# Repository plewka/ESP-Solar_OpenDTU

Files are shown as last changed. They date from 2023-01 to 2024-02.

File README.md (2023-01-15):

# ESP-Solar_OpenDTU
PCB for OpenDTU in Cable Branchbox, LineSupply w. Fuses, RS485/RS232-Olimex, Relais, DS2485 OneWire, I2C-Header...

Mechanically fits into quite compact HNS 989861-H01 wiring box (form closure only).
If not all features are used, even edged Wieland-Socket should fit.
LEDs need LightGuides: no. position-drawing and not included in material list 

Tradeoff: Very limited space, copyrighted code for ds2485

image::ESP-SolarV1.jpg

* WESP32-WROOM-based (internal or external antenna)

* 5x20 Fuseholder (Supply)
* Varistor
* HiLink Supplymodule f.e. 230V->3.3V

* 5x20 Fuseholder (Relais)
* Relais SANYOU 10A

* modern 1Wire-Controler DS2485
* programming Header (Shelly-Pinout)
* I2C+VCC+GND header
* 2x5 Ribbon Connector for Olimex' RS485/RS232-Modules
* LEDs (green: power, red:active, or:DS2485 GPIO)

* TTL serial connector f.e. for IR-Energy reading 
* robust cage clamps for external connections

The board was done for differend scenarios including HoymilesDTU, using different RF-Modules,
reading the new IR-Energy counters with "Volkszähler", measure distributed temerature locations 
with OneWire-Sensors and control of pool pump or heating elements, maybe some IR motion detection 
in the garage, interfacing RS485/Modbus/RS232 for Solar-Inverters etc. - CAN- and metering bus 
are missing, though.

Would be great to hear how you used it or modified it for!

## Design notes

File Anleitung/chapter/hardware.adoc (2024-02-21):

== ESP-Solar Hardware

Die vorliegende Hardware wurde universeller gebaut und hat zusätzliche Fähigkeiten, außer der Kommunikation mit den Invertern, die aber eine veränderte Firmware benötigen, um nutzbar zu sein.

.3D-Rendering ohne Klemmen
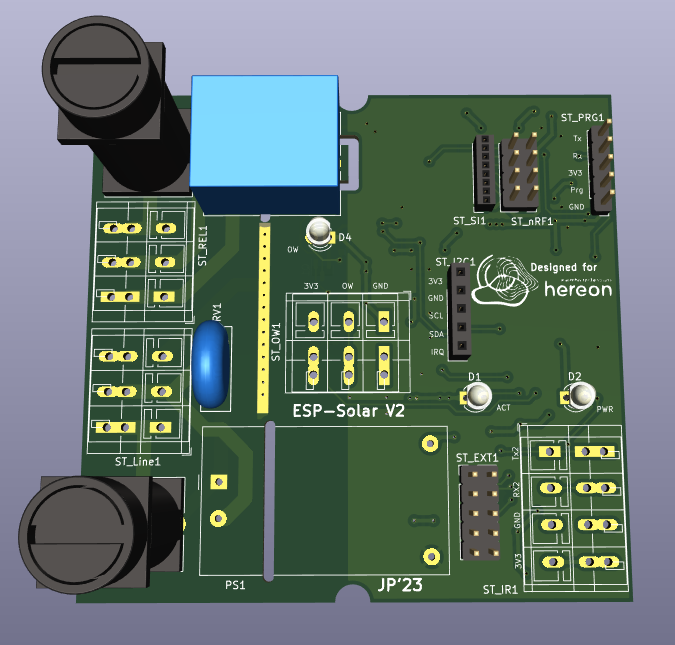
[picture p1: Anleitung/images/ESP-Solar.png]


=== Bauform
Wesentliches Designmerkmal war, dass die Baugruppe in eine relativ kleine Verteilerdose passt und ein Netzteil mitbringt, damit sie ohne ein Steckernetzteil direkt vom Stromnetz mit 230V~ betrieben werden kann. Netzspannung birgt immer eine große Lebensgefahr! Die Leiterplatte ist auf der Unterseite an den Lötstellen und auch an einem Schutzelement auf der Oberseite nicht isoliert und an der Oberfläche nur lackiert. Nicht berühren und Abschalten! 

=== (keine) Fixierung
Die Baugruppe ist nur durch Formschluss in der Dose fixiert. Es gibt ein spezielles Werkzeug für die Klemmen, was keinen Druck auf die Leiterplatte ausübt. Druck auf die Klemmen mit einem Schraubendreher wird auf empfindliche Bauteile an der Unterseite weitergegeben und wird diese zerstören. Die Baugruppe sollte an den Ecken, nach dem Anschrauben der Verteilerdose mit _säurefreiem_ Silikon befestigt werden. Normales Silikon enthält Essigsäure und wird die Leiterplatte zerfressen!
Es kann zielführend sein, kurze Anschlussdrähte mit zusätzlichen Dosensteckklemmen zu verwenden, zumal der L-Kontakt bei der ersten Version der Leiterplatte sehr schlecht erreichbar ist.

=== Schutzklasse
Die gewählte Verteilerdose hat eine Schutzklasse von IP67, d.h. sie hat schon recht gute Schaumdichtungen, allerdings hat dies immer Grenzen und ein Platz der regelmäßig nassgeregnet wird, ist sicher nicht für einen dauerhaften Betrieb geeignet und wird zur Ansammlung von Feuchtigkeit und Schäden führen.

=== Sicherung 
Das Netzteil ist mit einer Feinsicherung (5x20mm, Flink 400mA) und einem Varistor geschützt, was dem Gerät hoffentlich eine lange Lebensdauer beschert. Der Varistor schließt zu hohe Eingangsspannungen ab 350V~ kurz und löst damit zum Schutz die Sicherung aus. Daher darf das Gerät - z.B. bei Prüfungen der Installation - nicht mit höheren Prüfspannungen geprüft werden.
Vorsicht, den Varistor nicht berühren, seine Beine sind nicht isoliert und es ist möglich diese zu berühren! 

=== Antennenvarianten
Es gibt Varianten mit interner und externer WLAN-Antenne, je nach Bedarf. Die Ausführung hängt von der Bestückung des Prozessormoduls ab.
Mit interner Antenne ist Vorsicht geboten, diese nicht zu beschädigen. Bei Version 1 der Leiterplatte müssen die Aussparungen leicht aufgefeilt werden, damit die Platine 
beim Einbau nicht mit der Antenne verspannt.

=== LEDs

* Die grüne LED zeigt an, dass das Netzteil Spannung liefert. Sie sollte durchgehend leuchten. Tut sie es nicht, ist vermutlich die Sicherung kaputt oder es liegt keine Netzspannung an. 
* Die rote LED (GPIO25) kann z.B. aktiviert werden, wenn das Relais (GPIO33) angezogen ist. Sie ist aber nicht fest mit der Ansteuerung des Relais gekoppelt. 
* Eine orange LED könnte z.B. Aktivität auf dem OneWire-Bus oder die Überschreitung eines Grenzwerts anzeigen.

=== Lichtleiter

Wenn es nötig ist, die LEDs von Außen zu sehen, kann man Löcher in den Deckel bohren und Acryl-Licht-Leiter einbauen/einkleben.

Die Position (aus dem Zentrum in Ausrichtung mit lesbaren Logos gesehen) ist: 

[cols="1,1,1"]
|===
| *LED* | *X* | *Y*
| rot  | 17,1mm| -8,4mm 
| grün | 31,4mm | -8,4mm
| orange |-4,9mm | 14,7mm
|===

=== Schwierigkeiten
Gibt es Schwierigkeiten, kann man mit einem TTL-Seriell-Kabel (Vorsicht: +3.3V bei den Signalen, _keine_ Spannung einspeisen!) 
bei der Kodierung 8N1 mit 115200bps auf dem Programmierstecker "mithören", wo das Problem liegt. Es gibt auch in OpenDTU Info-Seiten, um die System- und Netzwerkeinstellungen 
usw. zu kontrollieren. Dort wird auch angezeigt, ob das Funkmodul erreichbar ist.

=== Pläne

.Schaltplan
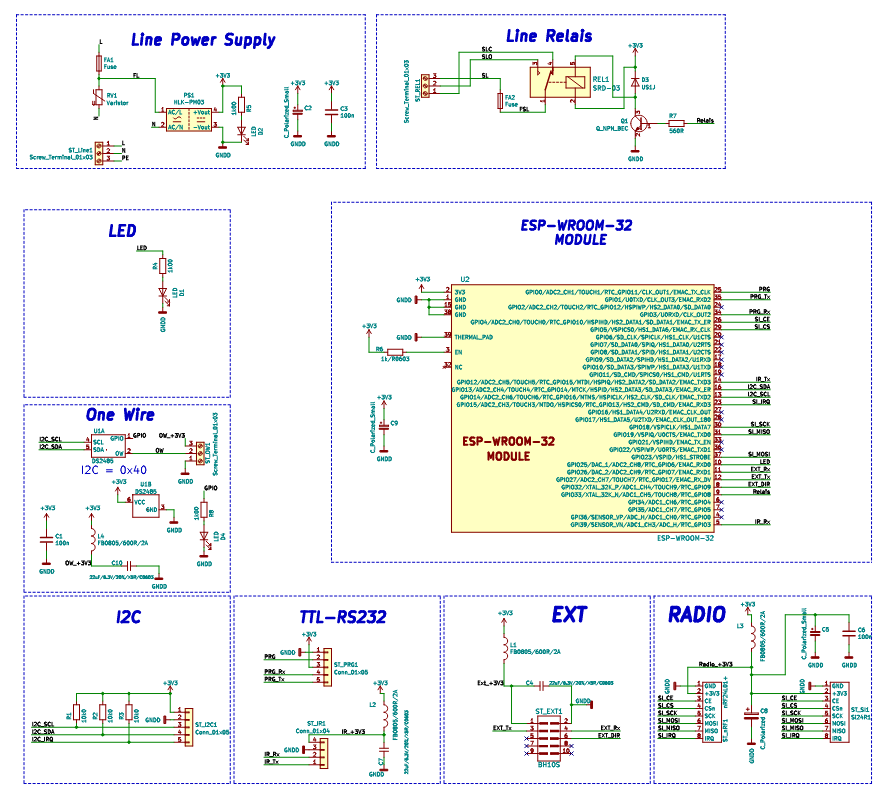
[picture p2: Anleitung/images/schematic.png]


.Bestückung Unterseite
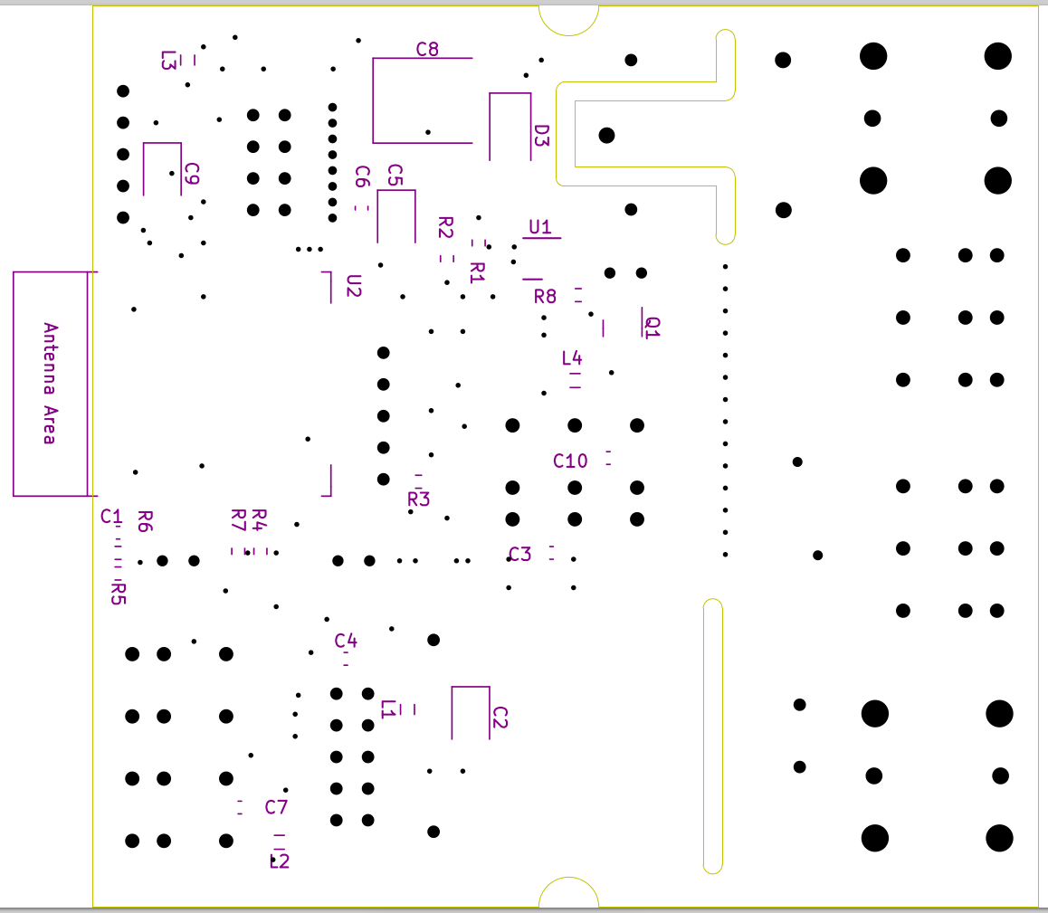
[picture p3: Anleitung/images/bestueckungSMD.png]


.Bestückung Unterseite
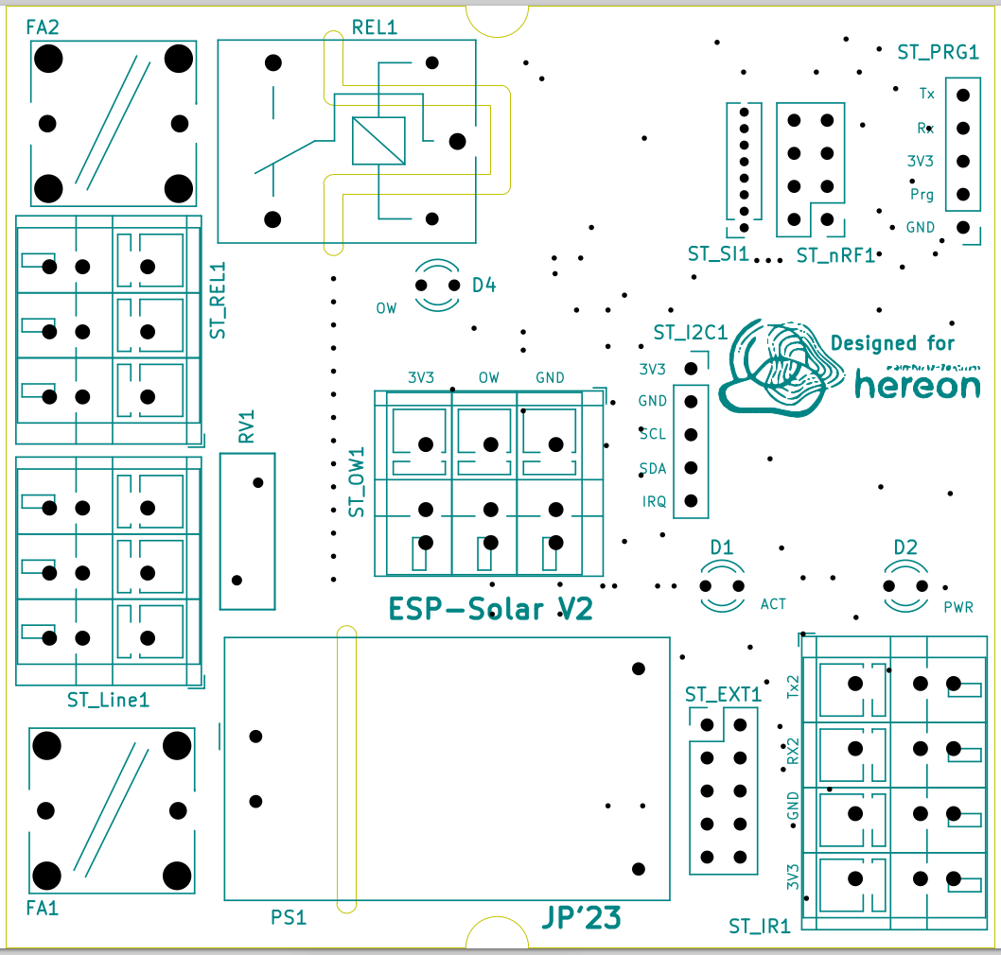
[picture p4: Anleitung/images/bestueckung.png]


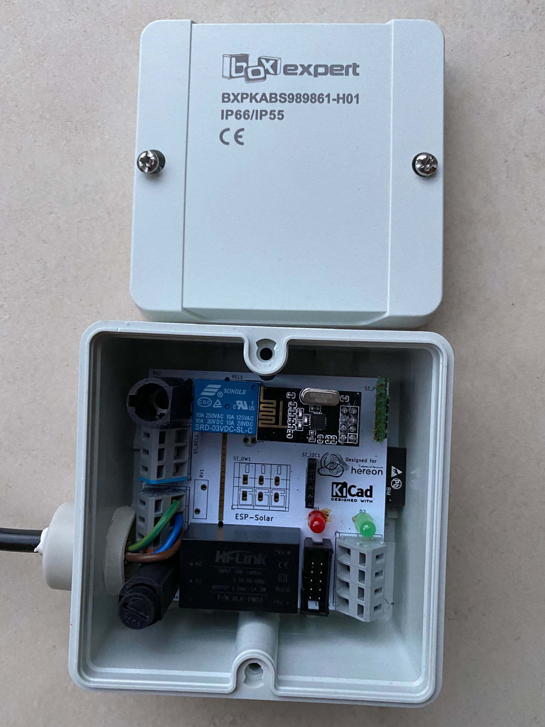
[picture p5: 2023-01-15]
ESP-SolarV1.jpg

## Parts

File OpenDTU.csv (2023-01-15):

ID | Bezeichner | Gehäuse | Stückzahl | Bezeichnung | Anbieter und Referenz
1 | ST_OW1,ST_Line1,ST_REL1 | TerminalBlock_WAGO_236-403_1x03_P5.00mm_45Degree | 3 | Screw_Terminal_01x03
2 | D1,D2,D4 | LED_D3.0mm_Clear | 3 | LED
3 | FA1,FA2 | Fuseholder_Cylinder-5x20mm_Bulgin_FX0456_Vertical_Closed | 2 | Fuse
4 | PS1 | Converter_ACDC_HiLink_HLK-PMxx | 1 | HLK-PM03
5 | ST_nRF1 | PinHeader_2x04_P2.54mm_Vertical | 1 | nRF24L01+
6 | ST_I2C1 | PinSocket_1x05_P2.54mm_Vertical | 1 | Conn_01x05
7 | ST_PRG1 | PinHeader_1x05_P2.54mm_Vertical | 1 | Conn_01x05
8 | REL1 | Relay_SPDT_SANYOU_SRD_Series_Form_C | 1 | SRD-03
9 | ST_EXT1 | PinHeader_2x05_P2.54mm_Vertical | 1 | BH10S
10 | ST_SI1 | PinSocket_1x08_P1.27mm_Vertical | 1 | Si24R1
11 | ST_IR1 | TerminalBlock_WAGO_236-404_1x04_P5.00mm_45Degree | 1 | Conn_01x04
12 | RV1 | RV_Disc_D12mm_W4.2mm_P7.5mm | 1 | Varistor
13 | C10,C7,C4 | C_0603_1608Metric | 3 | 22uF/6.3V/20%/X5R/C0603
14 | R3,R1,R2 | R_0603_1608Metric | 3 | 10k0
15 | R4,R5,R8 | R_0603_1608Metric | 3 | 1k00
16 | C6,C3,C1 | C_0603_1608Metric | 3 | 100n
17 | C2,C9,C5 | CP_EIA-3528-12_Kemet-T | 3 | C_Polarized_Small
18 | L4,L2,L3,L1 | L_0805_2012Metric | 4 | FB0805/600R/2A
19 | U1 | DFN-6-1EP_3x3mm_P0.95mm_EP1.7x2.6mm | 1 | DS2485
20 | D3 | D_SMA | 1 | US1J
21 | U2 | ESP32-WROOM-32E | 1 | ESP-WROOM-32
22 | Q1 | SOT-23 | 1 | Q_NPN_BEC
23 | C8 | CP_EIA-7260-38_AVX-R | 1 | C_Polarized
24 | R6 | R_0603_1608Metric | 1 | 1k/R0603
25 | R7 | R_0603_1608Metric | 1 | 560R

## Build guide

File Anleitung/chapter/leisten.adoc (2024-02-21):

=== Klemmleisten

Es gibt vier Klemmleisten im Gerät. 

==== Versorgung
Die Klemmleiste mit der orangen Abdeckplatte, ist für den Netzanschluss, die Energieversorgung gedacht. Es werden L, N und PE angeschlossen. PE wird nur für eine Schutzbarriere auf der Leiterplattenoberfläche (Gefahr durch Feuchtigkeit) verwendet. Die Belegung (von der Mitte aus gesehen) ist: PE, N, L.

==== Relais
Die Klemmleiste mit der blauen Abdeckplatte ist zum Anschluss des Relais gedacht. 
Die Belegung (aus Richtung Mitte) ist folgende: Öffner-, Schließer-, Mittelpolkontakt.
Das Relais hat eine eigene Sicherung am Mittelpolkontakt. Da es sich um ein 10A-Relais handelt, dürfen nur Lasten angeschlossen werden, die 2300Watt ohmsche Leistung nicht überschreiten - bei Motoren usw. auch durch den Anlauf noch deutlich weniger. Die Sicherung ist eine Feinsicherung (5x20mm, Träge 10A). Grundsätzlich ist die Spannung von den 230V~ der Versorgung völlig getrennt, innerhalb einer Verteilerdose dürfen aber keine verschiedenen Sicherungskreise verkabelt werden. Es gibt eine veränderte OpenDTU-Firmware, die das Relais steuern kann.

==== One-Wire
Die Klemmleiste mit der grauen Abdeckplatte in der Mitte der Leiterplatte bietet einen OneWire-Bus für Temperatursensoren. Der verwendete Controller kann zahlreiche Temperatursensoren über lange Distanzen verwalten und zugänglich machen. Es ist natürlich auch möglich, einen Temperatursensor direkt in die Verteilerdose zu klemmen, um die Innentemperatur zu ermitteln.
Die DS18B20-Sensoren gibt es als Bauteil im TO-92 Gehäuse, oder eingepresst für Tauchhülsen und Anlegeklammern.
Die Belegung (vom Netzteilblock aus gesehen) ist: Versorgung +3,3V, Onewire, Masse. Es gibt aktuell eine Firmware auf Basis von ESPHome, die diese Sensoren auswerten kann.

==== IR-Seriell
Die vierpolige Klemmleiste ist mit einer seriellen Schnittstelle mit TTL-Signalpegel belegt, um z.B. mit einem IR-Lesekopf (Volkszähler) moderne Gebäudeenergiezähler abzufragen.
Die Belegung (aus der Ecke gesehen) ist: +3V, Masse, Rx, Tx (GPI39, GPIO12). Dies wird gewöhnlich nicht die Anwendung zusammen mit OpenDTU sein, sondern ist eine weitere Einsatzmöglichkeit des Geräts.

=== Stiftleisten 

Der Aufdruck auf der Platine deutet auf deren Funktion. Bei Version 2 sind auch die einzelnen Signale beschriftet.

==== Programmierstecker
Die Stiftleiste an der Platinenkante ST_PRG über dem Logo ist der Programmierstecker.
Die Belegung (von der Leiterplattenmitte gesehen) ist folgende: Masse, Prg, +3.3V, Rx, Tx (GPIO0, GPIO3, GPIO1). Es ist übrigens die gleiche Belegung wie bei Shelly1.

==== Funkmodulstecker
Die doppelreihige Stiftleiste und jene mit dem kleinen Abstand daneben, tragen alternativ ein Funkmodul für die Kommunikation mit den Wechselrichtern.
Es gibt diese Module in zwei Varianten, daher gibt es dort zwei Steckerpositionen für den gleichen Zweck. Die Module mit dem kleinen Stecker sind gewöhnlich chinesische Nachbauten, 
während es für den großen Stecker sowohl Nachbauten, als auch Platinen mit dem orginalen reichweitenstärkeren nRF01+ gibt. 
Bei Version 1 der Leiterplatte sind die Kontakte 1+2 am zweireihigen Stecker vertauscht, weshalb eine hohe Steckleiste verbaut werden muss, mit der die Korrektur erfolgt.

==== I2C-Stecker
In der Mitte der Leiterplatte, neben Logo und roter LED, ist eine Stiftleiste ST_I2C, die für I2C Messsensoren wie z.B. den BME680 gedacht ist.
Die Belegung (von den Funksteckern aus gesehen) ist folgende: +3.3V, Masse, Clk, Data, Irq (GPIO14, GPIO13, GPIO15).

==== Olimex Seriell-Stecker
Die Stiftleiste für Flachbandstecker hat die Belegung zur Nutzung der Olimex-Adapter-Kabel für serielle Schnittstellen mit RS-485 oder RS-232.
Es es sind nur Betriebsspannung, Sende-, Empfangs- und Richtungssteuerungsleitung belegt. Auf den Halfduplex-RS485-Adaptern müssen entsprechend Brücken verändert werden.
Die Idee für diese Steckleiste ist die Verwendung des Geräts z.B. als ModbusRTU/TCP-MQTT-Gateway, z.B. in Verbindung mit der Firmware Tasmota, um entsprechende Energiezähler oder Wechselrichter abzufragen.

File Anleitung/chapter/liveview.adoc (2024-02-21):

=== LiveView-Anzeige

.Live View
 

Die Wechselrichter versorgen sich nur aus dem Sonnenlicht. Wenn sie mehr als den Eigenbedarf von den Solarpanels bekommen,
speisen sie die Energie ein. Sie unterscheiden daher Power und Power_DC ersteres ist die eigespeiste Leistung, letzteres das, was an Leistung von den Solarpanels kam. 

Die Wechselrichter gibt es mit 1,2 und vier Strings. Je nach Typ sieht die Darstellung dann anders aus.

Der Eigenbedarf ist ca. 1,5 Watt. Abends/morgens gibt es einen Zeitraum, in der der Wechselrichter erreichbar ist, aber noch keine Energie liefert.
Zwischen den beiden Power-Werten ergibt sich die Efficiency, der Wirkungsgrad.

Yield ist die Energieausbeute. Jeder Wechselrichter schreibt seine Gesamtbilanz und die jedes SolarPanels mit. Dabei erfasst er sowohl den aktuellen Tag als auch die 
Ausbeute, seit er erstmals aktiviert wurde.
Die elektrischen Parameter rund um Netzfrequenz, Spannung, Blindleistung nebst Powerfaktor werden auch dargestellt. 
Der Wechselrichter zeigt auch eine Temperatur an, sie scheint aber nicht besonders genau zu sein. Sicher lässt sich damit aber erkennen, ob er 
wegen hoher Temperatur ggf. in die Begrenzung gehen muss.

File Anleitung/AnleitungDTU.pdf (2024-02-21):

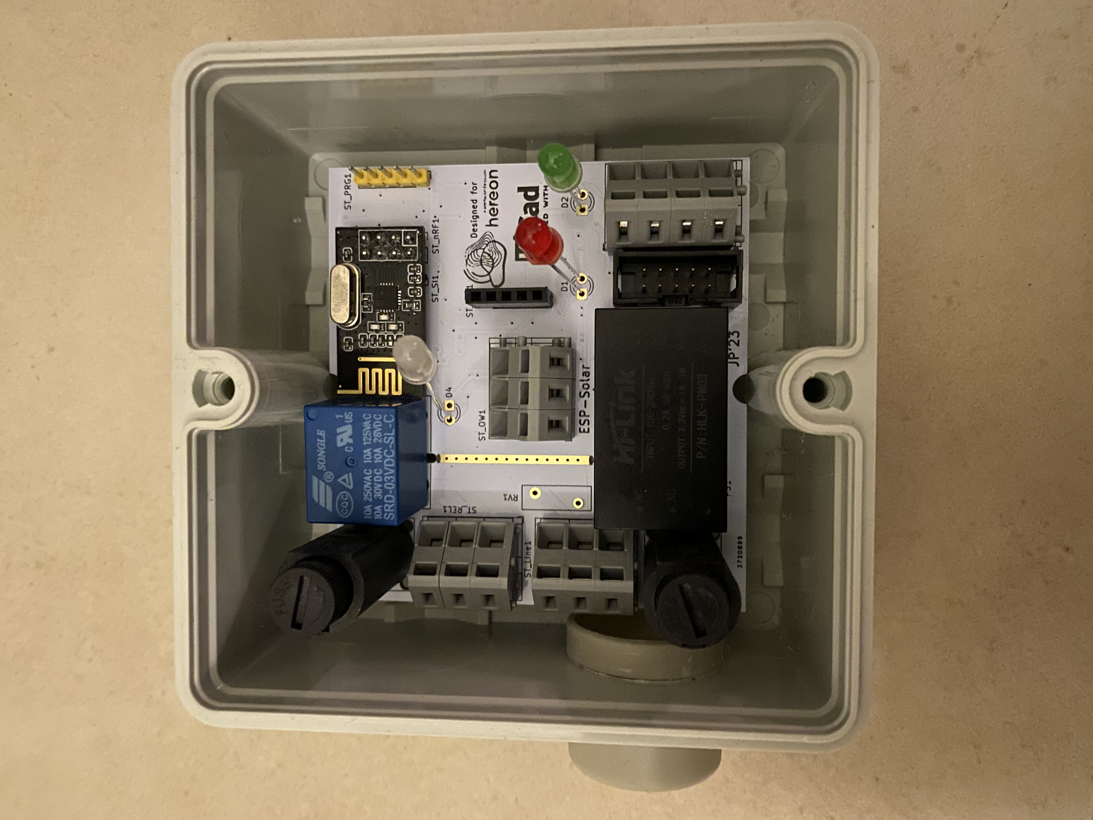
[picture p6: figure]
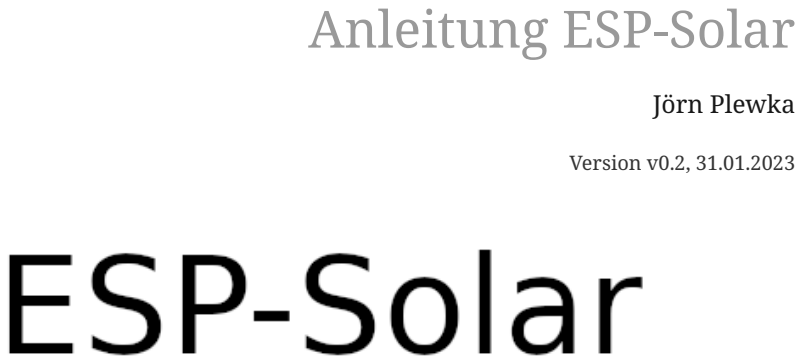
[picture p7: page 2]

# Anleitung ESP-Solar

### Jörn Plewka

Version v0.2, 31.01.2023

# Table of Contents

# Impressum

Projektdaten:
Die beschriebene Baugruppe ist in privater Zeit, mit privaten Ressourcen, für private Zwecke entstanden.
Da erkennbar war, dass sie auch für einfache wissenschaftliche Aufgaben nützlich sein könnte, ist sie dem Helmholtz Zentrum Hereon gewidmet.

Dies soll auf die wichtige gesellschaftliche Bedeutung der Forschung im Allgemeinen und des Zentrums im Besonderen hinweisen und Interesse dafür wecken.
Die Baugruppe folgt als OpenHardware dem Lizenzgedanken der GPL-2.0-Lizenz.

Das Forschungszentrum finden sie unter folgenen Angaben: Postfach: 1160
Max-Planck-Str.1
DE 21502 Geesthacht
Tel. +49 (0)4152 87-0
info@hereon.de | http://www.hereon.de

# OpenDTU

Für die Solarwechselrichter (engl. Inverter) der Firma Hoymiles kann man eine sogenannte "Digital Transfer Unit" für mehrere 100 Euro kaufen, welche mit den Wechselrichtern Kontakt aufnehmen kann. Die Inverter von Hoymiles werden auch unter anderen Markennamen verkauft, wie z.B. TSUN. Inzwischen gibt es zwei Serien bei Hoymiles, aber nur die ältere HM-xxxx nutzt dieses Nordic-Funkprotokoll.

Findige Leute haben das Gerät in mehreren Evolutionsstufen in OpenSource-Projekten nachgebaut. Das mündete in das großartige Projekt "OpenDTU". Die Screenshots in dieser Anleitung stammen überwiegend auch aus diesem Projekt!

https://github.com/tbnobody/OpenDTU

# Chapter 1. ESP-Solar Hardware

Die vorliegende Hardware wurde universeller gebaut und hat zusätzliche Fähigkeiten, außer der Kommunikation mit den Invertern, die aber eine veränderte Firmware benötigen, um nutzbar zu sein.


Figure 1. 3D-Rendering ohne Klemmen

# 1.1. Bauform

Wesentliches Designmerkmal war, dass die Baugruppe in eine relativ kleine Verteilerdose passt und ein Netzteil mitbringt, damit sie ohne ein Steckernetzteil direkt vom Stromnetz mit 230V~ betrieben werden kann. Netzspannung birgt immer eine große Lebensgefahr! Die Leiterplatte ist auf der Unterseite an den Lötstellen und auch an einem Schutzelement auf der Oberseite nicht isoliert und an der Oberfläche nur lackiert. Nicht berühren und Abschalten!

# 1.2. (keine) Fixierung

Die Baugruppe ist nur durch Formschluss in der Dose fixiert. Es gibt ein spezielles Werkzeug für die Klemmen, was keinen Druck auf die Leiterplatte ausübt. Druck auf die Klemmen mit einem Schraubendreher wird auf empfindliche Bauteile an der Unterseite weitergegeben und wird diese zerstören. Die Baugruppe sollte an den Ecken, nach dem Anschrauben der Verteilerdose mit säurefreiem Silikon befestigt werden. Normales Silikon enthält Essigsäure und wird die Leiterplatte zerfressen! Es kann zielführend sein, kurze Anschlussdrähte mit zusätzlichen Dosensteckklemmen zu verwenden, zumal der L-Kontakt bei der ersten Version der Leiterplatte sehr schlecht erreichbar ist.

# 1.3. Schutzklasse

Die gewählte Verteilerdose hat eine Schutzklasse von IP67, d.h. sie hat schon recht gute Schaumdichtungen, allerdings hat dies immer Grenzen und ein Platz der regelmäßig nassgeregnet wird, ist sicher nicht für einen dauerhaften Betrieb geeignet und wird zur Ansammlung von Feuchtigkeit und Schäden führen.

# 1.4. Sicherung

Das Netzteil ist mit einer Feinsicherung (5x20mm, Flink 400mA) und einem Varistor geschützt, was dem Gerät hoffentlich eine lange Lebensdauer beschert. Der Varistor schließt zu hohe Eingangsspannungen ab 350V~ kurz und löst damit zum Schutz die Sicherung aus. Daher darf das Gerät - z.B. bei Prüfungen der Installation - nicht mit höheren Prüfspannungen geprüft werden. Vorsicht, den Varistor nicht berühren, seine Beine sind nicht isoliert und es ist möglich diese zu berühren!

# 1.5. Antennenvarianten

Es gibt Varianten mit interner und externer WLAN-Antenne, je nach Bedarf. Die Ausführung hängt von der Bestückung des Prozessormoduls ab. Mit interner Antenne ist Vorsicht geboten, diese nicht zu beschädigen. Bei Version 1 der Leiterplatte müssen die Aussparungen leicht aufgefeilt werden, damit die Platine beim Einbau nicht mit der Antenne verspannt.

# 1.6. LEDs

- Die grüne LED zeigt an, dass das Netzteil Spannung liefert. Sie sollte durchgehend leuchten. Tut sie es nicht, ist vermutlich die Sicherung kaputt oder es liegt keine Netzspannung an.
- Die rote LED (GPIO25) kann z.B. aktiviert werden, wenn das Relais (GPIO33) angezogen ist. Sie ist aber nicht fest mit der Ansteuerung des Relais gekoppelt.
- Eine orange LED könnte z.B. Aktivität auf dem OneWire-Bus oder die Überschreitung eines Grenzwerts anzeigen.

# 1.7. Lichtleiter

Wenn es nötig ist, die LEDs von Außen zu sehen, kann man Löcher in den Deckel bohren und Acryl-Licht-Leiter einbauen/einkleben.

Die Position (aus dem Zentrum in Ausrichtung mit lesbaren Logos gesehen) ist:

LED | X | Y
rot | 17,1mm | -8,4mm
grün | 31,4mm | -8,4mm
orange | -4,9mm | 14,7mm

# 1.8. Schwierigkeiten

Gibt es Schwierigkeiten, kann man mit einem TTL-Seriell-Kabel (Vorsicht: +3.3V bei den Signalen, keine Spannung einspeisen!) bei der Kodierung 8N1 mit 115200bps auf dem Programmierstecker "mithören", wo das Problem liegt. Es gibt auch in OpenDTU Info-Seiten, um die System- und Netzwerkeinstellungen usw. zu kontrollieren. Dort wird auch angezeigt, ob das Funkmodul erreichbar ist.

# 1.9. Pläne


Figure 2. Schaltplan

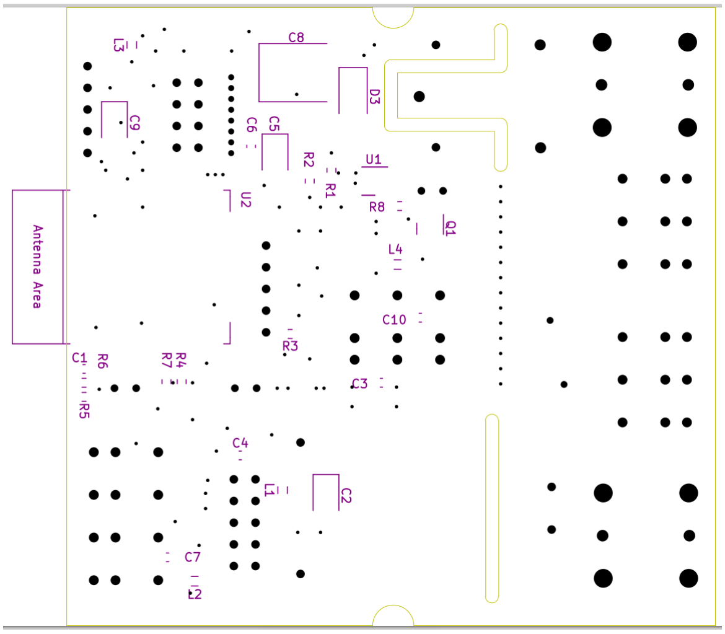
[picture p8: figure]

Figure 3. Bestückung Unterseite


Figure 4. Bestückung Unterseite

# 1.10. Klemmleisten

Es gibt vier Klemmleisten im Gerät.

### 1.10.1. Versorgung

Die Klemmleiste mit der orangen Abdeckplatte, ist für den Netzanschluss, die Energieversorgung gedacht. Es werden L, N und PE angeschlossen. PE wird nur für eine Schutzbarriere auf der Leiterplattenoberfläche (Gefahr durch Feuchtigkeit) verwendet. Die Belegung (von der Mitte aus gesehen) ist: PE, N, L.

### 1.10.2. Relais

Die Klemmleiste mit der blauen Abdeckplatte ist zum Anschluss des Relais gedacht. Die Belegung (aus Richtung Mitte) ist folgende: Öffner-, Schließer-, Mittelpolkontakt. Das Relais hat eine eigene

Sicherung am Mittelpolkontakt. Da es sich um ein 10A-Relais handelt, dürfen nur Lasten angeschlossen werden, die 2300Watt ohmsche Leistung nicht überschreiten - bei Motoren usw. auch durch den Anlauf noch deutlich weniger. Die Sicherung ist eine Feinsicherung (5x20mm, Träge 10A). Grundsätzlich ist die Spannung von den 230V~ der Versorgung völlig getrennt, innerhalb einer Verteilerdose dürfen aber keine verschiedenen Sicherungskreise verkabelt werden. Es gibt eine veränderte OpenDTU-Firmware, die das Relais steuern kann.

### 1.10.3. One-Wire

Die Klemmleiste mit der grauen Abdeckplatte in der Mitte der Leiterplatte bietet einen OneWire-Bus für Temperatursensoren. Der verwendete Controller kann zahlreiche Temperatursensoren über lange Distanzen verwalten und zugänglich machen. Es ist natürlich auch möglich, einen Temperatursensor direkt in die Verteilerdose zu klemmen, um die Innentemperatur zu ermitteln. Die DS18B20-Sensoren gibt es als Bauteil im TO-92 Gehäuse, oder eingepresst für Tauchhülsen und Anlegeklammern. Die Belegung (vom Netzteilblock aus gesehen) ist: Versorgung +3,3V, Onewire, Masse. Es gibt aktuell eine Firmware auf Basis von ESPHome, die diese Sensoren auswerten kann.

### 1.10.4. IR-Seriell

Die vierpolige Klemmleiste ist mit einer seriellen Schnittstelle mit TTL-Signalpegel belegt, um z.B. mit einem IR-Lesekopf (Volkszähler) moderne Gebäudeenergiezähler abzufragen. Die Belegung (aus der Ecke gesehen) ist: +3V, Masse, Rx, Tx (GPI39, GPIO12). Dies wird gewöhnlich nicht die Anwendung zusammen mit OpenDTU sein, sondern ist eine weitere Einsatzmöglichkeit des Geräts.

# 1.11. Stiftleisten

Der Aufdruck auf der Platine deutet auf deren Funktion. Bei Version 2 sind auch die einzelnen Signale beschriftet.

### 1.11.1. Programmierstecker

Die Stiftleiste an der Platinenkante ST_PRG über dem Logo ist der Programmierstecker. Die Belegung (von der Leiterplattenmitte gesehen) ist folgende: Masse, Prg, +3.3V, Rx, Tx (GPIO0, GPIO3, GPIO1). Es ist übrigens die gleiche Belegung wie bei Shelly1.

### 1.11.2. Funkmodulstecker

Die doppelreihige Stiftleiste und jene mit dem kleinen Abstand daneben, tragen alternativ ein Funkmodul für die Kommunikation mit den Wechselrichtern. Es gibt diese Module in zwei Varianten, daher gibt es dort zwei Steckerpositionen für den gleichen Zweck. Die Module mit dem kleinen Stecker sind gewöhnlich chinesische Nachbauten, während es für den großen Stecker sowohl Nachbauten, als auch Platinen mit dem orginalen reichweitenstärkeren nRF01+ gibt. Bei Version 1 der Leiterplatte sind die Kontakte 1+2 am zweireihigen Stecker vertauscht, weshalb eine hohe Steckleiste verbaut werden muss, mit der die Korrektur erfolgt.

### 1.11.3. I2C-Stecker

In der Mitte der Leiterplatte, neben Logo und roter LED, ist eine Stiftleiste ST_I2C, die für I2C

Messsensoren wie z.B. den BME680 gedacht ist. Die Belegung (von den Funksteckern aus gesehen) ist folgende: +3.3V, Masse, Clk, Data, Irq (GPIO14, GPIO13, GPIO15).

### 1.11.4. Olimex Seriell-Stecker

Die Stiftleiste für Flachbandstecker hat die Belegung zur Nutzung der Olimex-Adapter-Kabel für serielle Schnittstellen mit RS-485 oder RS-232. Es es sind nur Betriebsspannung, Sende-, Empfangs-und Richtungssteuerungsleitung belegt. Auf den Halfduplex-RS485-Adaptern müssen entsprechend Brücken verändert werden. Die Idee für diese Steckleiste ist die Verwendung des Geräts z.B. als ModbusRTU/TCP-MQTT-Gateway, z.B. in Verbindung mit der Firmware Tasmota, um entsprechende Energiezähler oder Wechselrichter abzufragen.

# Chapter 2. Einrichtung OpenDTU

# 2.1. Anmeldung ins eigene WLAN

Wenn OpenDTU aufgespielt ist, meldet es sich nach dem Einschalten als WLAN-Access-Point. Das Gerät macht also ein eigenes WLAN auf, bei dem man sich z.B. mit dem Handy anmelden kann. Das ist auch der erste Schritt.

- Passwort: openDTU42
- Webseite: http://192.168.4.1

Das WLAN heißt OpenDTU-xxxxxx, wobei das xxxxxx aus der WLAN-MAC-Kennung des Prozessors im Gerät erzeugt wird, also individuell ist.

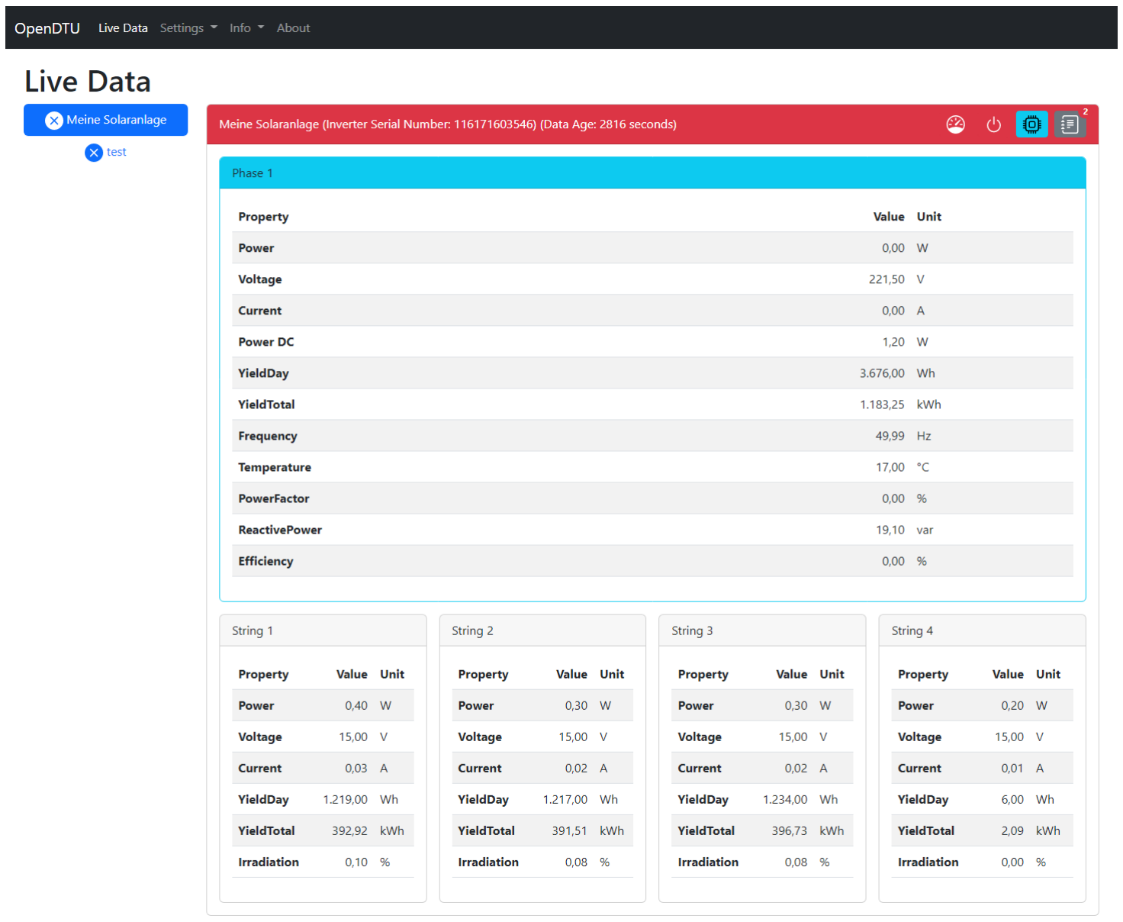
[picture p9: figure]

Figure 5. LiveView

- Benutzer: admin
- Passwort: openDTU42

# 2.2. Einstellungen

Die Schritte, die man in OpenDTU erledigen muss, sind:

1. Namen des Geräts und das Passwort ändern (beim Passwort wird das aktiv gefordert, sonst werden die Wechselrichter später nicht gelesen!)
2. Die Inverter mit ihrer Seriennummer eintragen, ihnen einen Namen geben und die 1-4 Eingänge mit den Solarzellen sinnvoll benennen
3. gucken, ob die Verbindung zum Zeitserver (NTP) korrekt läuft (läuft sie nicht, kommen auch keine Daten vom Inverter)
4. handelt es sich um einen 800W-Inverter, und man betreibt ein Balkonkraftwerk, muss die Begrenzung noch auf 600W dauerhaft gesetzt werden
5. wenn man Heimautomatisiserung mit Homeassistant oder einem anderen MQTT-Server betreibt, muss man den auch noch eintragen, damit die Daten übermittelt werden

Um Einstellungen ändern zu können, muss man sich mit obigen Zugangsdaten anmelden. Als erstes wird man das eigene WLAN eintragen und einen Gerätenamen vergeben, den man sich merken kann, z.B. OpenDTU ohne die Endung.

Fritzbox-Hinweis

Bei der Fritzbox: http://fritz.box einloggen und dann WLAN-Geräte…und auf das Gerät klicken. Die Fritzbox bietet eine Namensauflösung aller angeschlossenen Geräte. Wenn man den Namen des Geräts weiß (anfangs ist das opendtu-xxxxxx - den kann man später aber selber vergeben, s.u.) kann man diesen zukünftig direkt in den Browser eintippen und muss sich keine ggf. veränderne IP-Nummer (192.168.178.x o.ä.) merken.

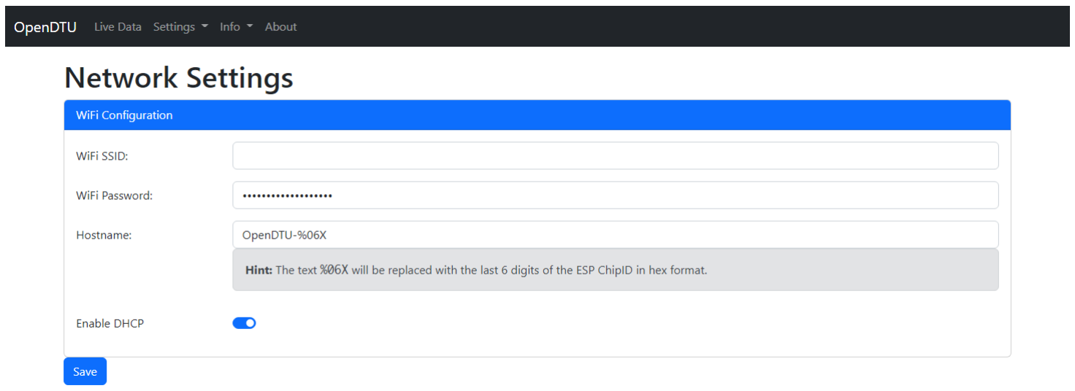
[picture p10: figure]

Figure 6. Settings → NetworkAdmin

Wenn man das eigene WLAN eingestellt hat und die Verbindung erfolgreich war, wird der Access-Point nach einiger Zeit deaktiviert. Während das Gerät versucht, sich mit dem eigenen WLAN zu verbinden, ist der AccessPoint eine Zeit lang ggf. nicht erreichbar. Da hilft dann nur warten. War die Einstellung erfolgreich, wird man auf dem eigenen WLAN-Router ein neues Gerät im WLAN finden. Natürlich muss dazu dann mit dem Handy auch wieder zurück in das eigene WLAN.

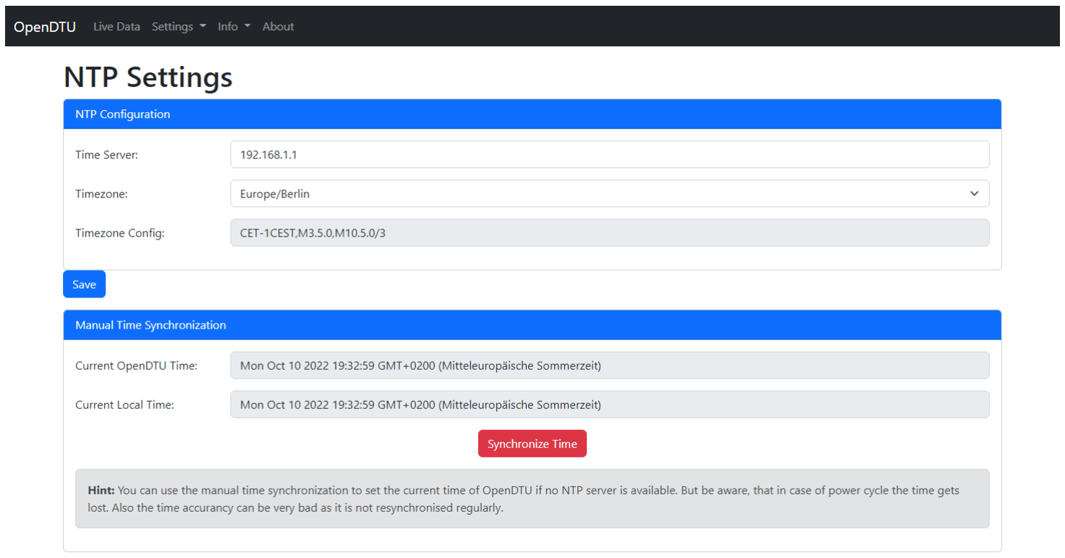
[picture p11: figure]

Figure 7. Settings → NTPAdmin

Die Einstellungen für NTP (Zeitserver) düften in den meisten Fällen direkt funktionieren. Es ist wichtig, dass die Zeit korrekt empfangen wird, sonst bekommt man keine Daten von den Wechselrichtern.

# 2.3. Homeautomation

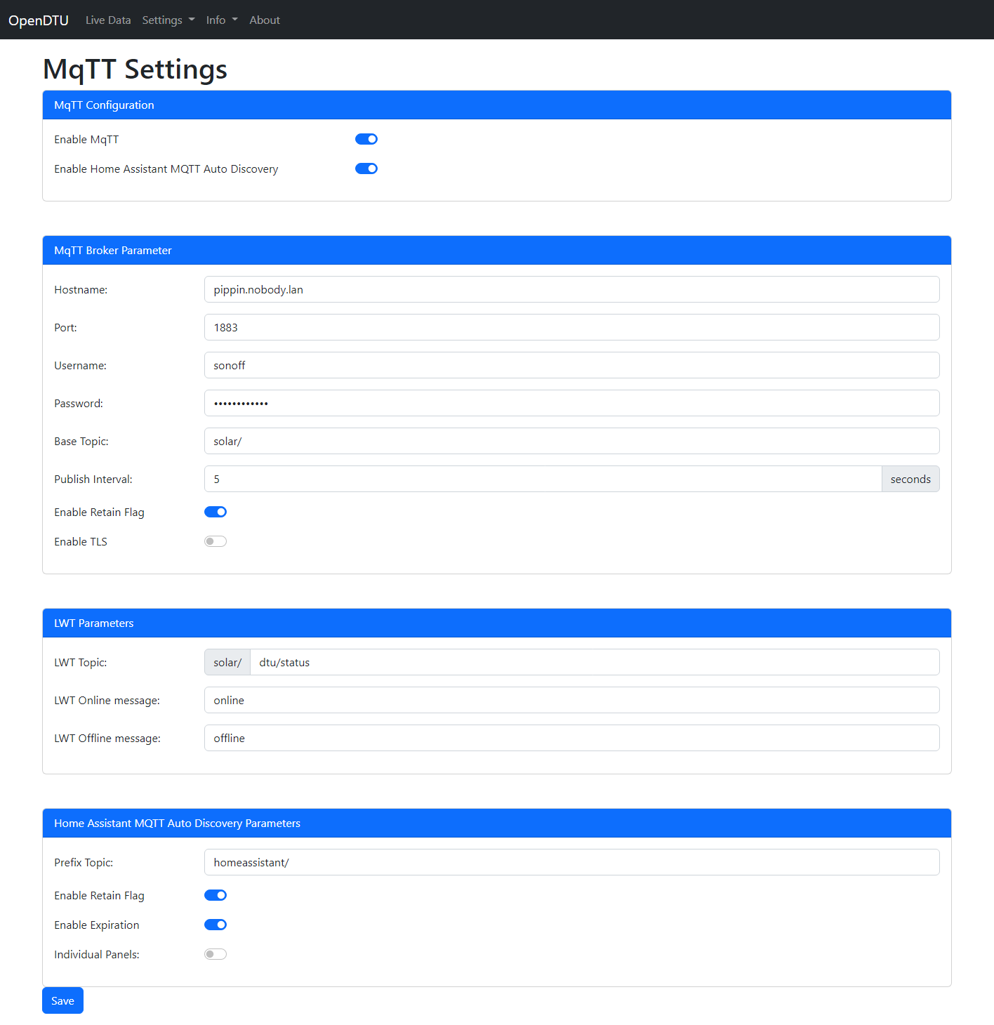
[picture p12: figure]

Figure 8. Settings → MqttAdmin

Die MQTT-Einstellungen benötigt man für entsprechende Heimautomatisierungsdienste, wie z.B. Homeassistant.

Die Unterstützung zur Integration in Homeassistant ist in OpenDTU integriert. Homeassistant findet das OpenDTU-Gerät und ermöglicht nach wenigen Klicks die Anzeige auf dem gewünschten Dashboard. Man kann auf dem Dashboard dann alle Wechselrichter zusammenrechnen oder die Wetterprognose anzeigen.

[homeassistant] | screenshots/homeassistant.png
Figure 9. Integration Homeassistant

Sobald ein MQTT-Brockerdienst läuft, kann man z.B. mit dem Programm MqTT-Explorer den Datenverkehr (Topics und Werte) ansehen, der dann so gegliedert ist:

[MQTT Explorer] | screenshots/MQTT_Explorer.png
Figure 10. MqTT Daten mitlesen

# 2.4. Wechselrichter eintragen

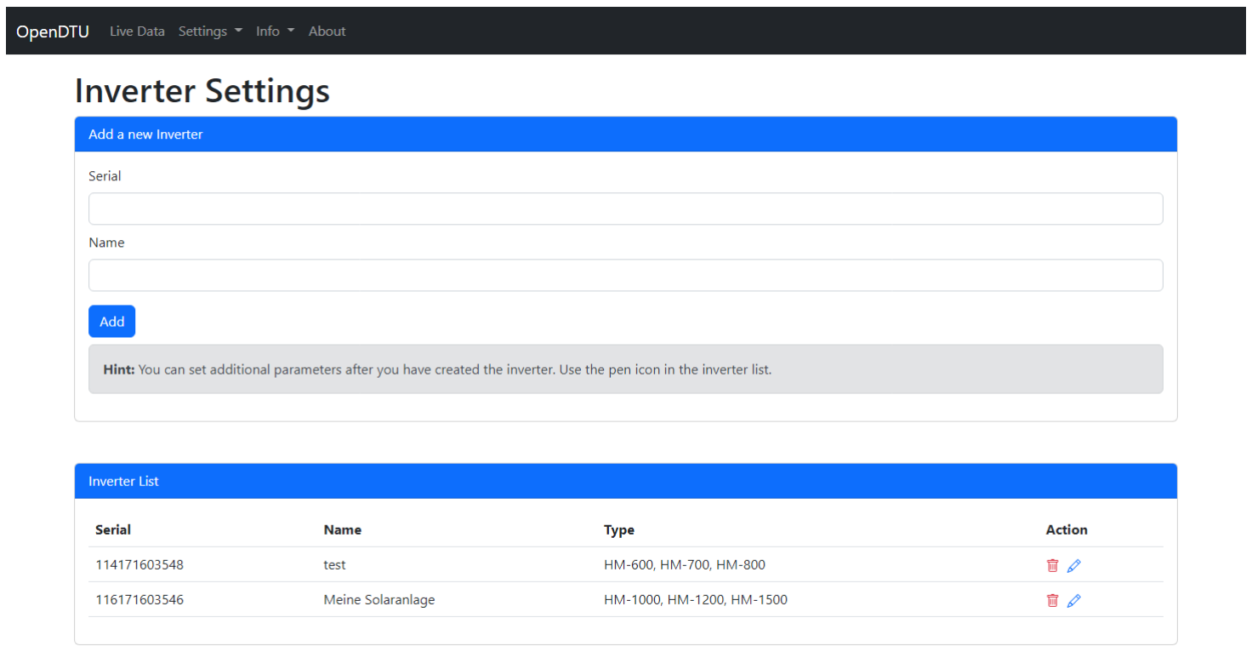
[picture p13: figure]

Figure 11. Settings → Inverter Admin

In diesen Settings trägt man die Seriennummern der Inverter ein. Auf den Invertern befindet sich die Seriennummer einmal als Aufkleber und einmal als Abziehaufkleber. Da das Gerät draußen ggf. die Beschriftung verliert, ist die Idee des Herstellers, den Aufkleber auf die DTU-Einheit zu kleben. Wenn die Nummer verloren ist, hat man letztlich keine Chance den Wechselrichter jemals wieder abzufragen. Die Seriennummer ist wie der Schlüssel.

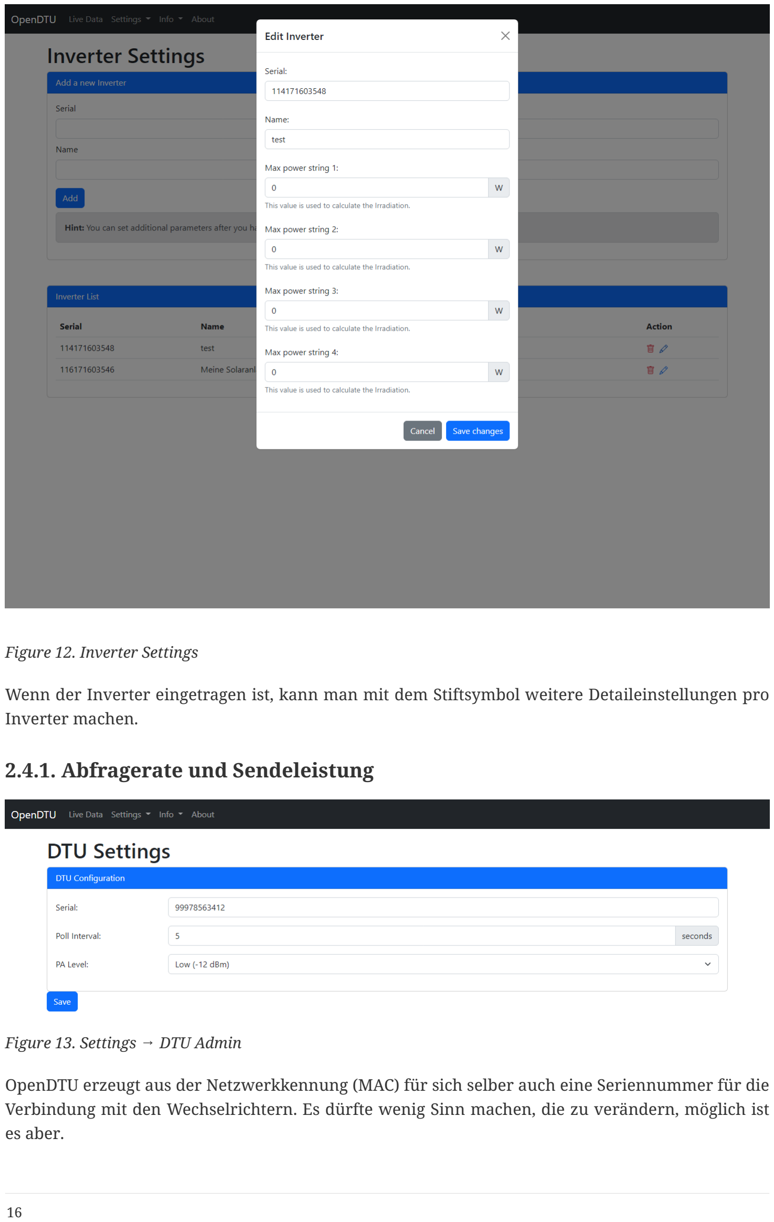
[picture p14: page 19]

Figure 12. Inverter Settings

Wenn der Inverter eingetragen ist, kann man mit dem Stiftsymbol weitere Detaileinstellungen pro Inverter machen.

### 2.4.1. Abfragerate und Sendeleistung

Figure 13. Settings → DTU Admin

OpenDTU erzeugt aus der Netzwerkkennung (MAC) für sich selber auch eine Seriennummer für die Verbindung mit den Wechselrichtern. Es dürfte wenig Sinn machen, die zu verändern, möglich ist es aber.

Die Abfragerate ist auf einmal alle 5 sec durch die Regularien zur Funknutzung begrenzt. Daher trifft maximal alle 5 sec. ein neuer Wert ein. Bei schlechtem Empfang wird auch mal ein Datensatz fehlen. Die Sendeleistung des Funkempfängers lässt sich erhöhen. Das hilft, wenn die Wechselrichter nicht mitbekommen, dass sie abgefragt werden. Allerdings erhöhen sie selber wohl nicht die Sendeleistung, weshalb der Empfänger dann das schwache Signal der Wechselrichter korrekt empfangen muss. Vermutlich wird es dann nur helfen, das OpenDTU-Gerät näher an die Wechselrichter zu bringen.

### 2.4.2. Firmware

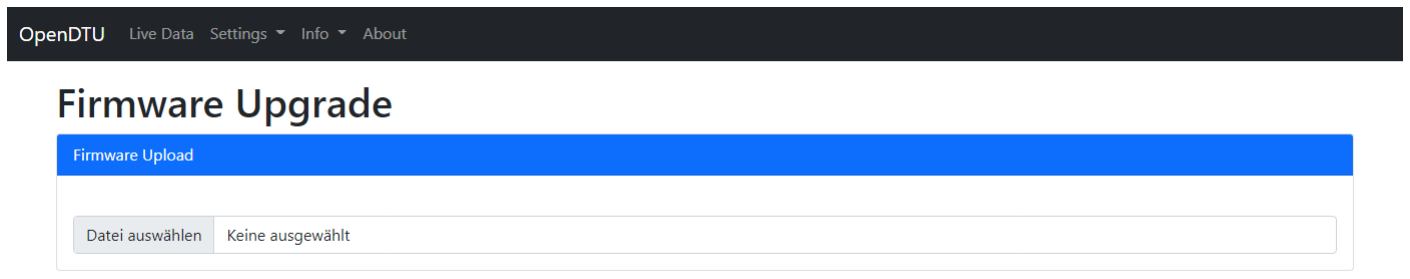
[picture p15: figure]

Figure 14. Firmware Upgrade

In diesem Dialog lässt sich die Firmware aktualisieren. Allerdings muss die Firmware hinsichtlich Belegung der Signale am Prozessor auch passen! Man wird sie nicht im Internet finden.

Die installierte Firmware kann abweichend per MQTT relais=1/relais=0 das Relais ansteuern.

board = esp32dev
build_flags = ${env.build_flags}
-DHOYMILES_PIN_MISO=19
-DHOYMILES_PIN_MOSI=23
-DHOYMILES_PIN_SCLK=18
-DHOYMILES_PIN_IRQ=15
-DHOYMILES_PIN_CE=4
-DHOYMILES
_PIN_CS=5

### 2.4.3. Backup/Werksreset

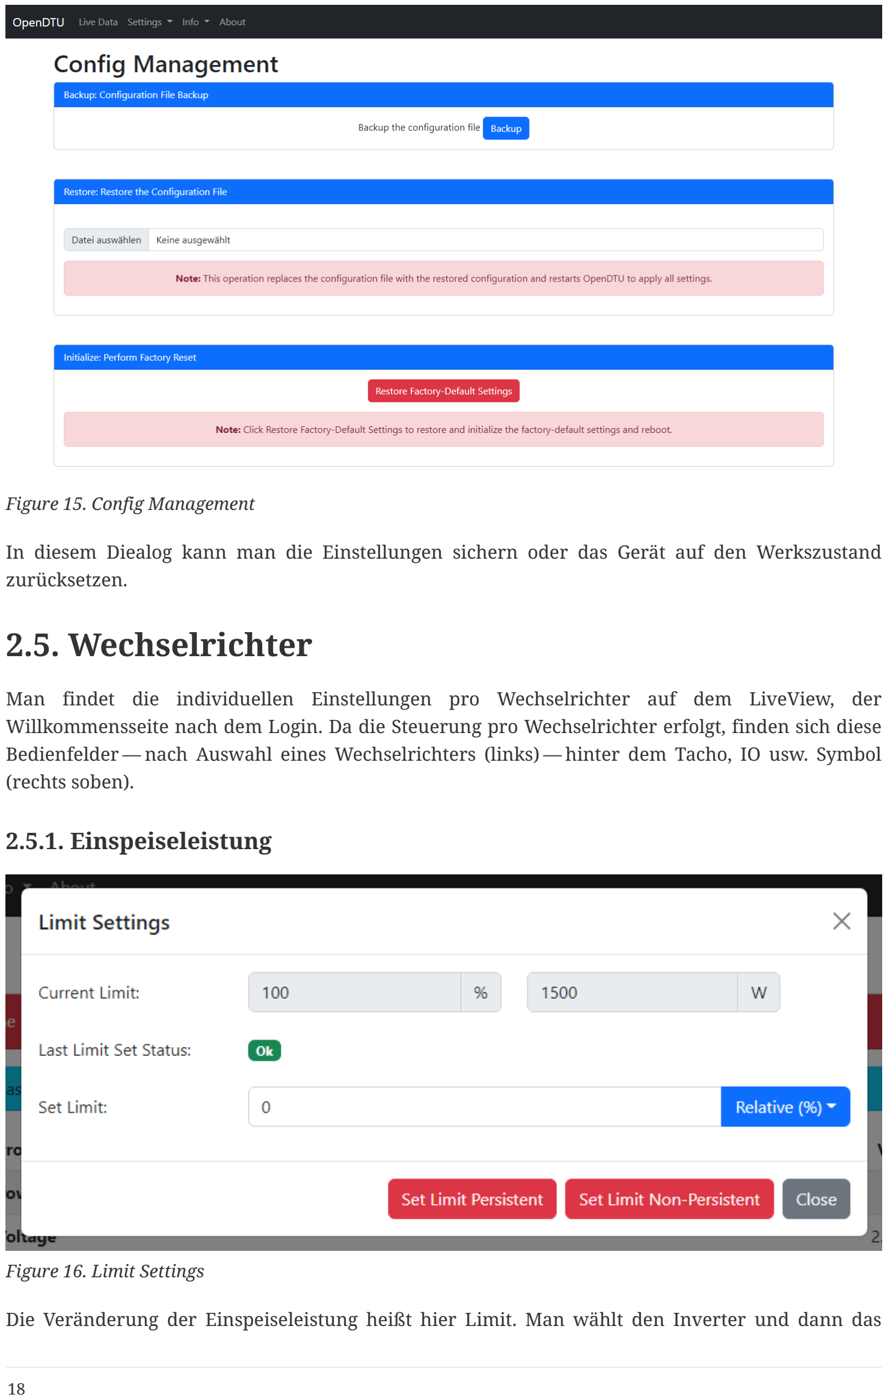
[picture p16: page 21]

Figure 15. Config Management

In diesem Diealog kann man die Einstellungen sichern oder das Gerät auf den Werkszustand zurücksetzen.

# 2.5. Wechselrichter

Man findet die individuellen Einstellungen pro Wechselrichter auf dem LiveView, der Willkommensseite nach dem Login. Da die Steuerung pro Wechselrichter erfolgt, finden sich diese Bedienfelder — nach Auswahl eines Wechselrichters (links) — hinter dem Tacho, IO usw. Symbol (rechts soben).

### 2.5.1. Einspeiseleistung

Figure 16. Limit Settings

Die Veränderung der Einspeiseleistung heißt hier Limit. Man wählt den Inverter und dann das

### 2.5.2. Abschalten

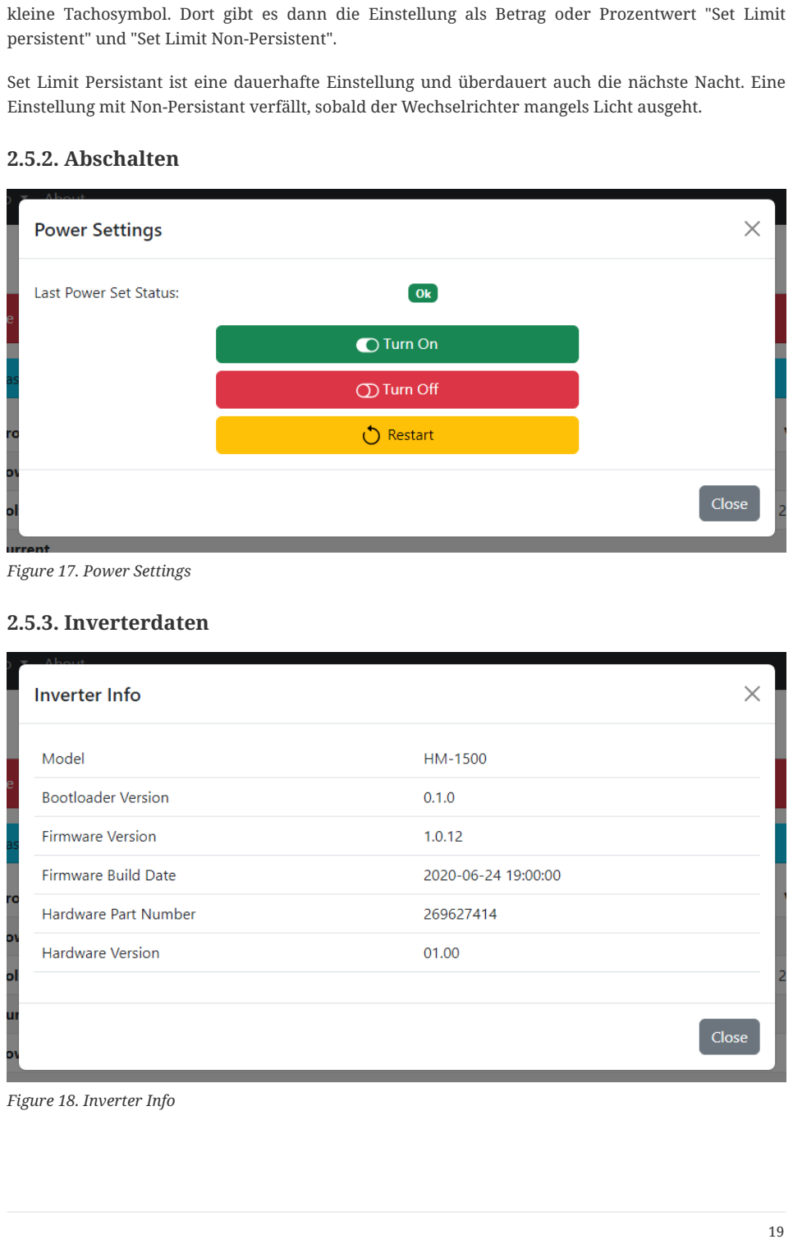
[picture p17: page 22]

kleine Tachosymbol. Dort gibt es dann die Einstellung als Betrag oder Prozentwert "Set Limit persistent" und "Set Limit Non-Persistent".

Set Limit Persistant ist eine dauerhafte Einstellung und überdauert auch die nächste Nacht. Eine Einstellung mit Non-Persistant verfällt, sobald der Wechselrichter mangels Licht ausgeht.

Figure 17. Power Settings

### 2.5.3. Inverterdaten

Figure 18. Inverter Info

# 2.6. Info

Es gibt auch in OpenDTU Info-Seiten, um die System- und Netzwerkeinstellungen usw. zu kontrollieren. In den Systeminfos wird z.B. auch angezeigt, ob das Funkmodul erreichbar ist.

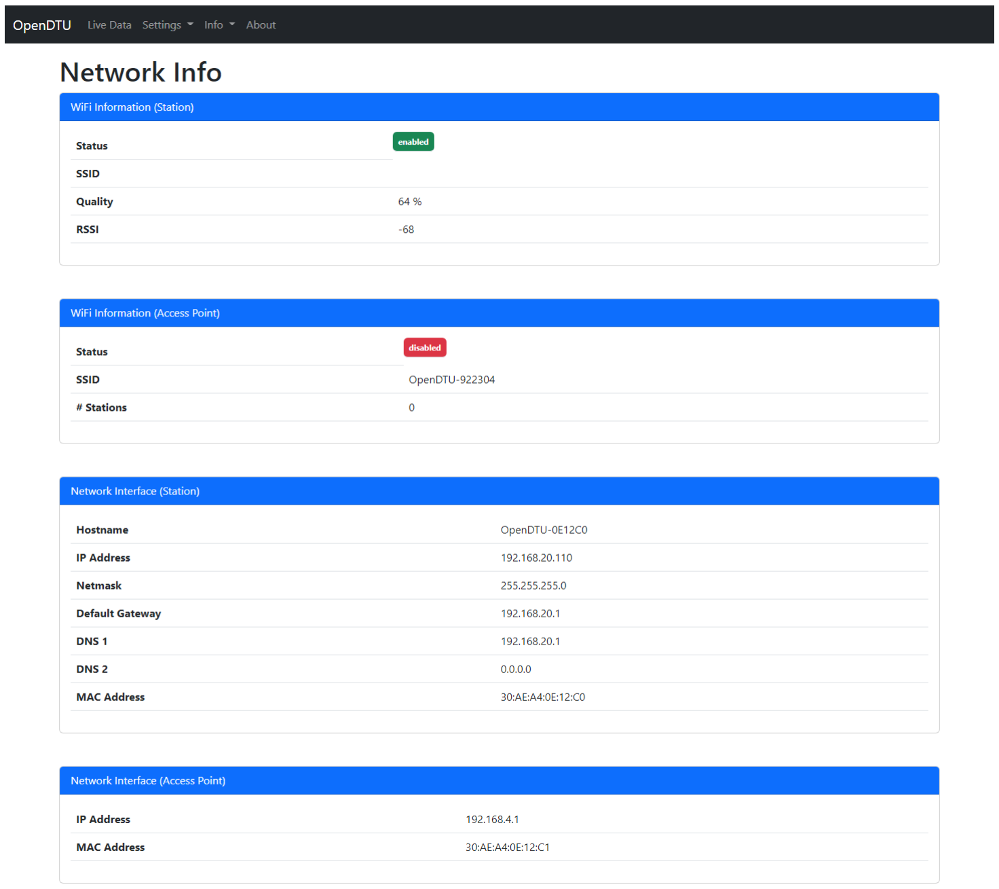
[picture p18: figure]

Figure 19. Network Info

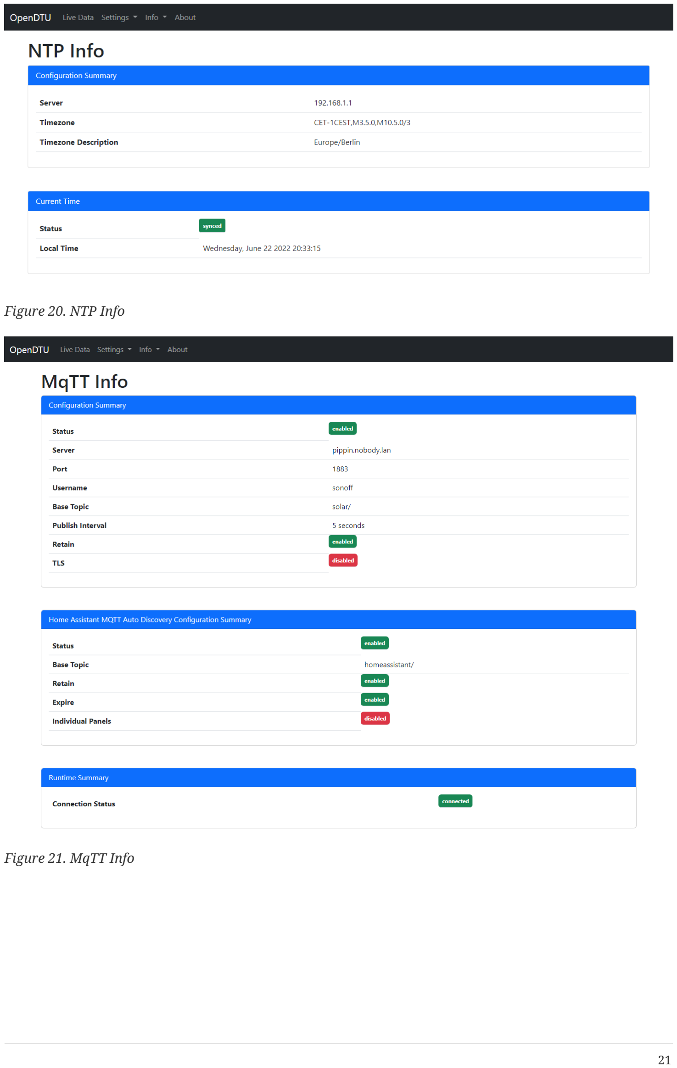
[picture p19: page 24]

Figure 20. NTP Info

Figure 21. MqTT Info

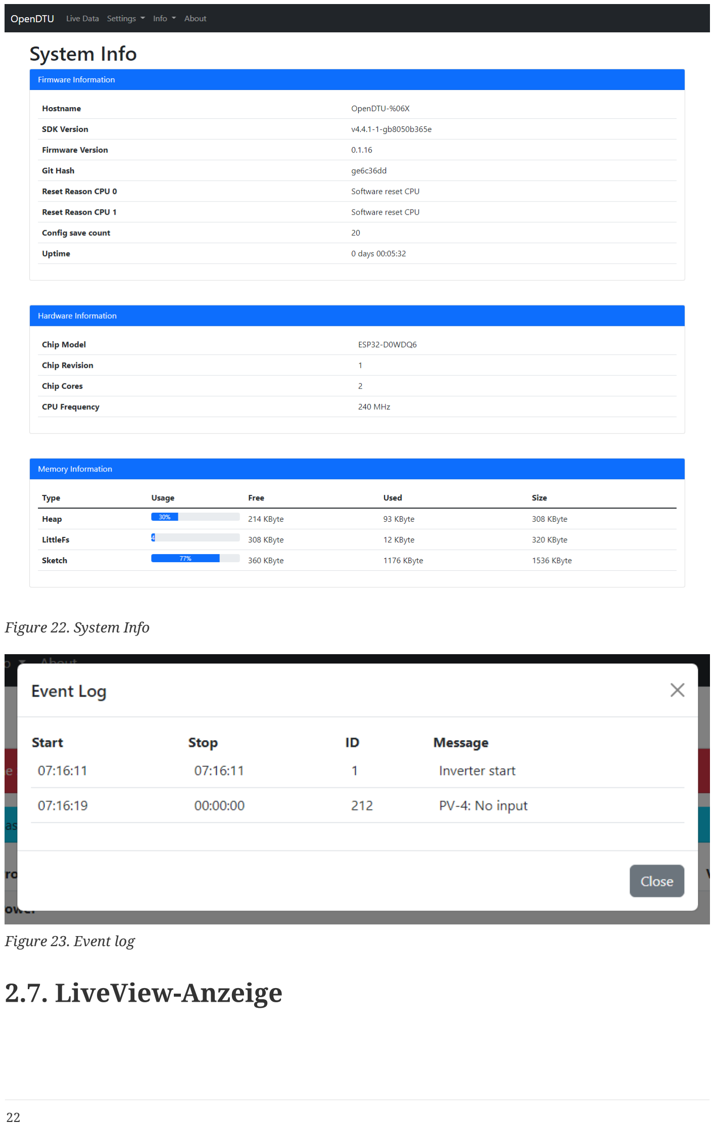
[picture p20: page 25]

Figure 22. System Info

Figure 23. Event log

# 2.7. LiveView-Anzeige

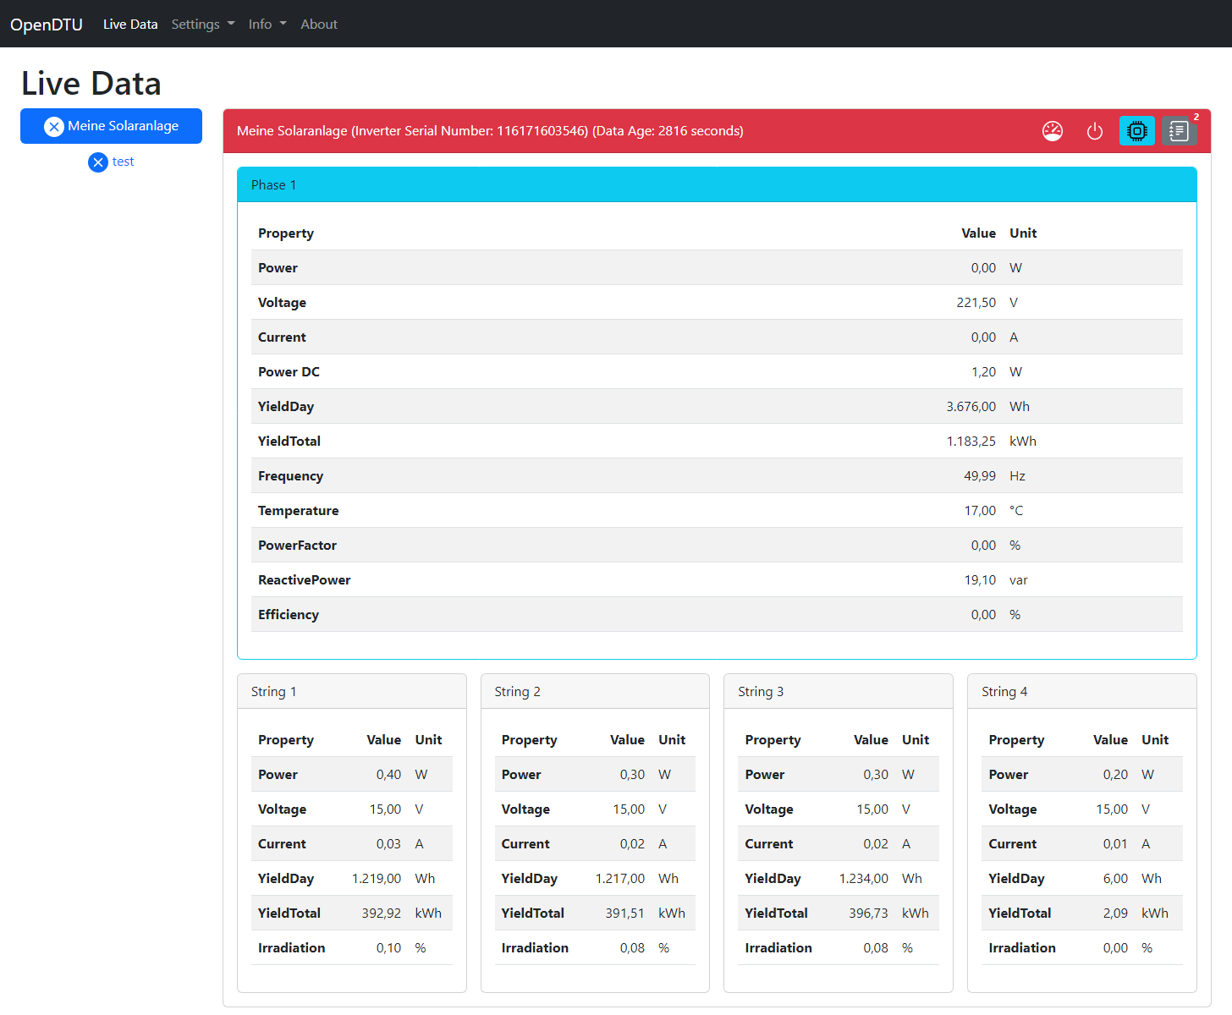
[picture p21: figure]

Figure 24. Live View

Die Wechselrichter versorgen sich nur aus dem Sonnenlicht. Wenn sie mehr als den Eigenbedarf von den Solarpanels bekommen, speisen sie die Energie ein. Sie unterscheiden daher Power und Power_DC ersteres ist die eigespeiste Leistung, letzteres das, was an Leistung von den Solarpanels kam.

Die Wechselrichter gibt es mit 1,2 und vier Strings. Je nach Typ sieht die Darstellung dann anders aus.

Der Eigenbedarf ist ca. 1,5 Watt. Abends/morgens gibt es einen Zeitraum, in der der Wechselrichter erreichbar ist, aber noch keine Energie liefert. Zwischen den beiden Power-Werten ergibt sich die Efficiency, der Wirkungsgrad.

Yield ist die Energieausbeute. Jeder Wechselrichter schreibt seine Gesamtbilanz und die jedes SolarPanels mit. Dabei erfasst er sowohl den aktuellen Tag als auch die Ausbeute, seit er erstmals aktiviert wurde. Die elektrischen Parameter rund um Netzfrequenz, Spannung, Blindleistung nebst Powerfaktor werden auch dargestellt. Der Wechselrichter zeigt auch eine Temperatur an, sie scheint aber nicht besonders genau zu sein. Sicher lässt sich damit aber erkennen, ob er wegen hoher Temperatur ggf. in die Begrenzung gehen muss.

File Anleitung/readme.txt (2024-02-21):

This is old state and only in german. 
Maybe it is still usefull in some cases.

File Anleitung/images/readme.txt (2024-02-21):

ToDo: 
How to use hierarchical asciidocs in GitHub?!
Screenshots of OpenDTU are missing. PDF contains foreign ones.

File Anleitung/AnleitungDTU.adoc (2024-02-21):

= Anleitung ESP-Solar
:author: Jörn Plewka
:email: joern.plewka@hereon.de
:revnumber: v0.2
:revdate: 31.01.2023
:doctype: book
:encoding: utf-8
:lang: de
:toc: left
:toclevels: 3
//:toc: macro
:showtitle:
//https://github.com/asciidocfx/AsciidocFX/issues/130
//https://github.com/asciidocfx/AsciidocFX/issues/114
//FRONT COVER PAGE
//PURE IMAGE PAGE ONLY, BEFORE TITLE PAGE
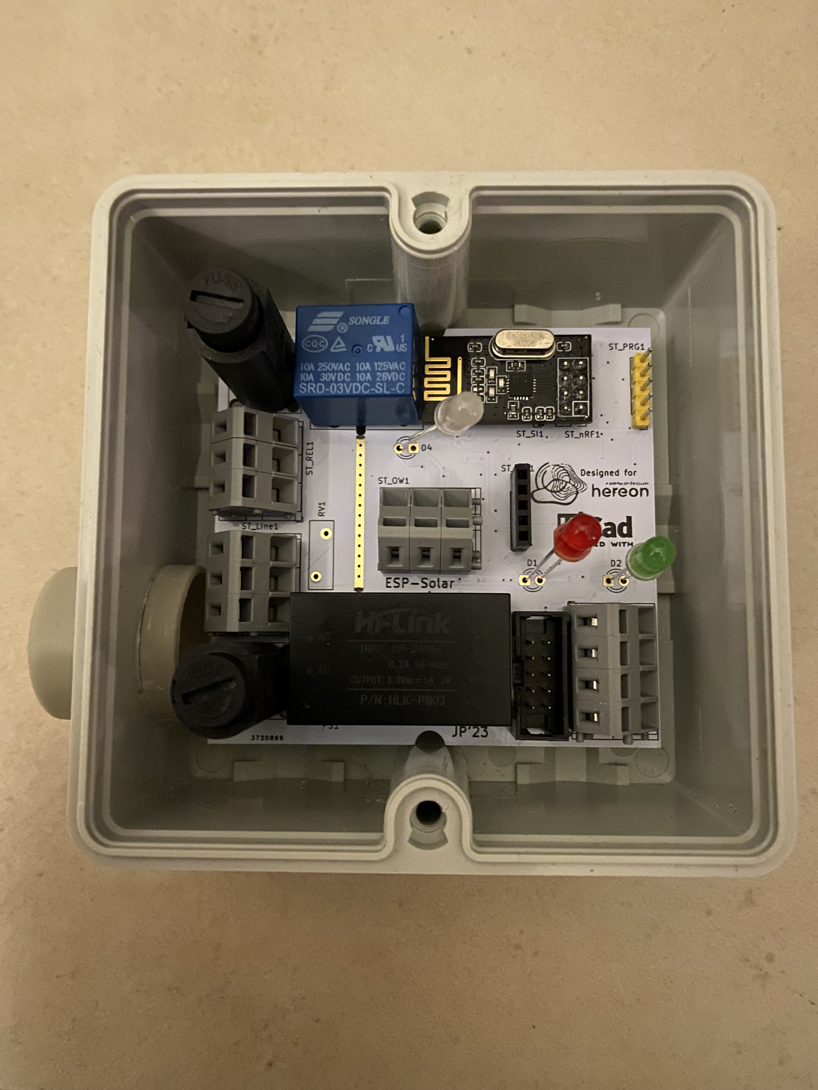
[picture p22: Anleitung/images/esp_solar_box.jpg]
:front-cover-image: 
//TITLE PAGE
:title-page:
//ADD IMAGE IN TITLE PAGE 
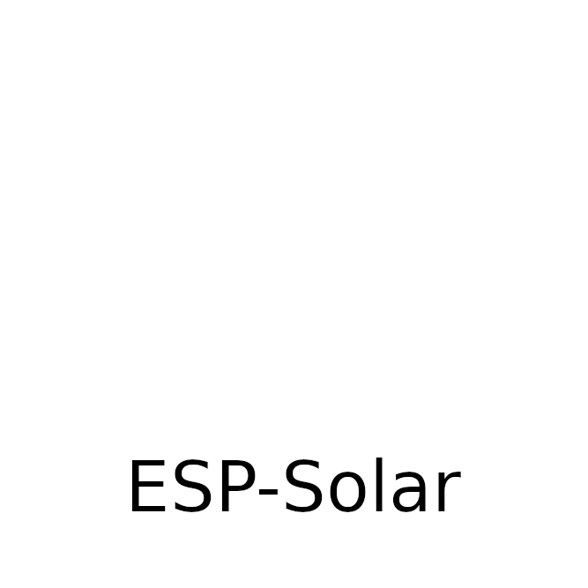
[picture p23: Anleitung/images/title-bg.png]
:title-page-background-image: 
//:title-logo-image: 
:chapterdir: chapter
:icons: image 
:icontype: svg
:iconsdir: icons
:imagesdir: images

////
Organize your book chapter by chapter
////

:sectnums!:

include::{chapterdir}/legal.adoc[]

:sectnums:
:toc:
//toc::[]
:toc-title: Inhaltsverzeichnis

:chapter-label: 

include::{chapterdir}/einleitung.adoc[]

include::{chapterdir}/hardware.adoc[]

include::{chapterdir}/leisten.adoc[]

include::{chapterdir}/wlan.adoc[]

include::{chapterdir}/einrichtung.adoc[]

include::{chapterdir}/einstellungen.adoc[]

include::{chapterdir}/info.adoc[]

include::{chapterdir}/liveview.adoc[]

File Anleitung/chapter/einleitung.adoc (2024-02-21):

= OpenDTU

Für die Solarwechselrichter (engl. Inverter) der Firma Hoymiles kann man eine sogenannte "Digital Transfer Unit" für mehrere 100 Euro kaufen, welche 
mit den Wechselrichtern Kontakt aufnehmen kann. Die Inverter von Hoymiles werden auch unter anderen Markennamen verkauft, wie z.B. TSUN. 
Inzwischen gibt es zwei Serien bei Hoymiles, aber nur die ältere HM-xxxx nutzt dieses Nordic-Funkprotokoll.  

Findige Leute haben das Gerät in mehreren Evolutionsstufen in OpenSource-Projekten nachgebaut. Das mündete in das großartige Projekt "OpenDTU". Die Screenshots in dieser Anleitung stammen überwiegend auch aus diesem Projekt!

https://github.com/tbnobody/OpenDTU

Die Weiterführung des Projekts nennt sich OpenDTU-OnBattery und nutzt den Wechselrichter als Netzeinspeisung aus einer Batterie und Victron-Regler um mit Solarpanels einen Akku zu laden. Das System leistet dann mit einer Energiemessung eine Nulleinspeisung mit Akkupufferung.

https://github.com/helgeerbe/OpenDTU-OnBattery

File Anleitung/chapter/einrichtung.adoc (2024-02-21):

=== Einstellungen

Die Schritte, die man in OpenDTU erledigen muss, sind:

1. Namen des Geräts und das Passwort ändern (beim Passwort wird das aktiv gefordert, sonst werden die Wechselrichter später nicht gelesen!)
2. Die Inverter mit ihrer Seriennummer eintragen, ihnen einen Namen geben und die 1-4 Eingänge mit den Solarzellen sinnvoll benennen
3. gucken, ob die Verbindung zum Zeitserver (NTP) korrekt läuft (läuft sie nicht, kommen auch keine Daten vom Inverter)
4. handelt es sich um einen 800W-Inverter, und man betreibt ein Balkonkraftwerk, muss die Begrenzung noch auf 600W _dauerhaft_ gesetzt werden
5. wenn man Heimautomatisiserung mit Homeassistant oder einem anderen MQTT-Server betreibt, muss man den auch noch eintragen, damit die Daten übermittelt werden

Um Einstellungen ändern zu können, muss man sich mit obigen Zugangsdaten anmelden. Als erstes wird man das eigene WLAN eintragen und einen Gerätenamen vergeben, den man sich merken kann, z.B. OpenDTU ohne die Endung.

**Fritzbox-Hinweis**

Bei der Fritzbox: http://fritz.box einloggen und dann WLAN-Geräte...und auf das Gerät klicken.
Die Fritzbox bietet eine Namensauflösung aller angeschlossenen Geräte. Wenn man den Namen des Geräts weiß (anfangs ist das opendtu-xxxxxx - den 
kann man später aber selber vergeben, s.u.) kann man diesen zukünftig direkt in den Browser eintippen und muss sich keine 
ggf. veränderne IP-Nummer (192.168.178.x o.ä.) merken.

.Settings -> NetworkAdmin


Wenn man das eigene WLAN eingestellt hat und die Verbindung erfolgreich war, wird der Access-Point nach einiger Zeit deaktiviert.
Während das Gerät versucht, sich mit dem eigenen WLAN zu verbinden, ist der AccessPoint eine Zeit lang ggf. nicht erreichbar. Da hilft dann nur warten.
War die Einstellung erfolgreich, wird man auf dem eigenen WLAN-Router ein neues Gerät im WLAN finden. Natürlich muss dazu dann mit dem Handy auch wieder zurück in das eigene WLAN. 

.Settings -> NTPAdmin


Die Einstellungen für NTP (Zeitserver) düften in den meisten Fällen direkt funktionieren. Es ist wichtig, dass die Zeit korrekt empfangen wird, sonst bekommt man keine Daten von den Wechselrichtern.

=== Homeautomation

.Settings -> MqttAdmin


Die MQTT-Einstellungen benötigt man für entsprechende Heimautomatisierungsdienste, wie z.B. Homeassistant.

Die Unterstützung zur Integration in Homeassistant ist in OpenDTU integriert. Homeassistant findet das OpenDTU-Gerät und ermöglicht nach wenigen Klicks die Anzeige
auf dem gewünschten Dashboard. Man kann auf dem Dashboard dann alle Wechselrichter zusammenrechnen oder die Wetterprognose anzeigen.

.Integration Homeassistant
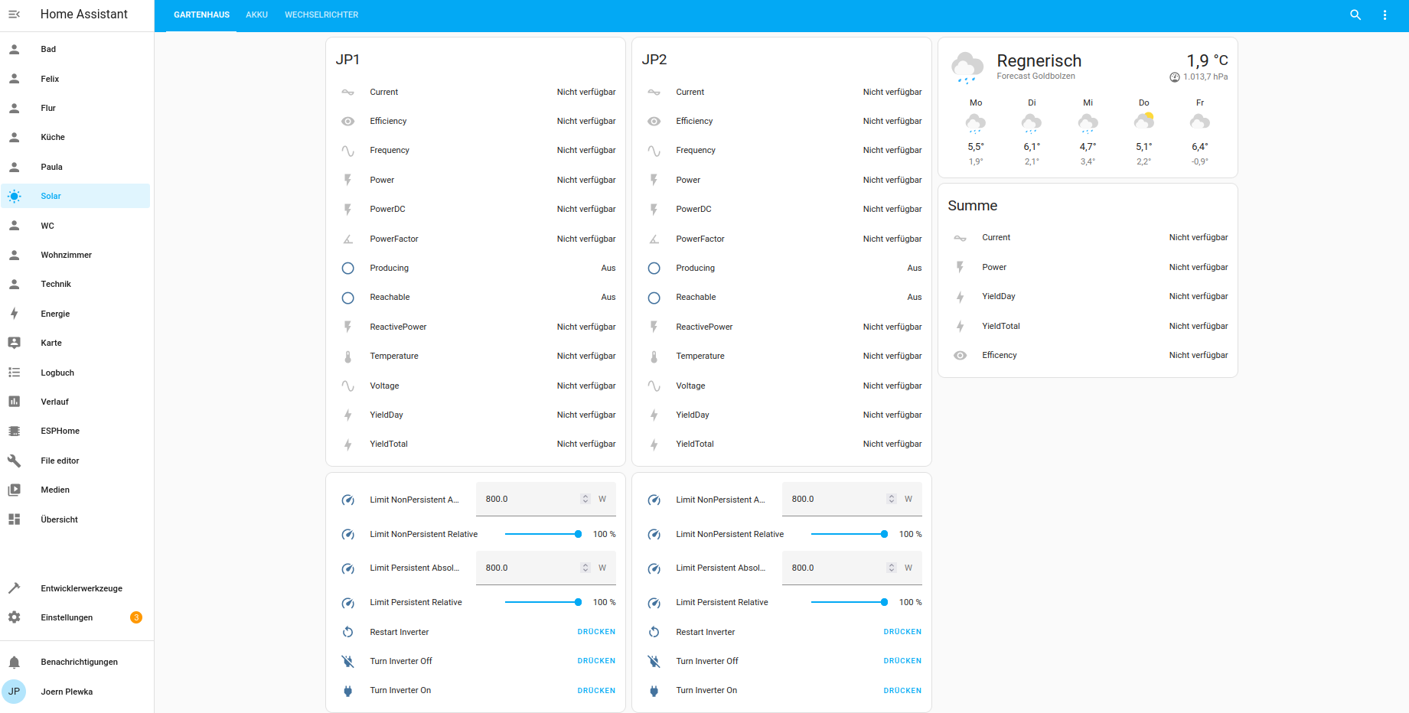
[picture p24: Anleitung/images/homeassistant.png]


Sobald ein MQTT-Brockerdienst läuft, kann man z.B. mit dem Programm MqTT-Explorer den Datenverkehr (Topics und Werte) ansehen, der dann so gegliedert ist:

.MqTT Daten mitlesen
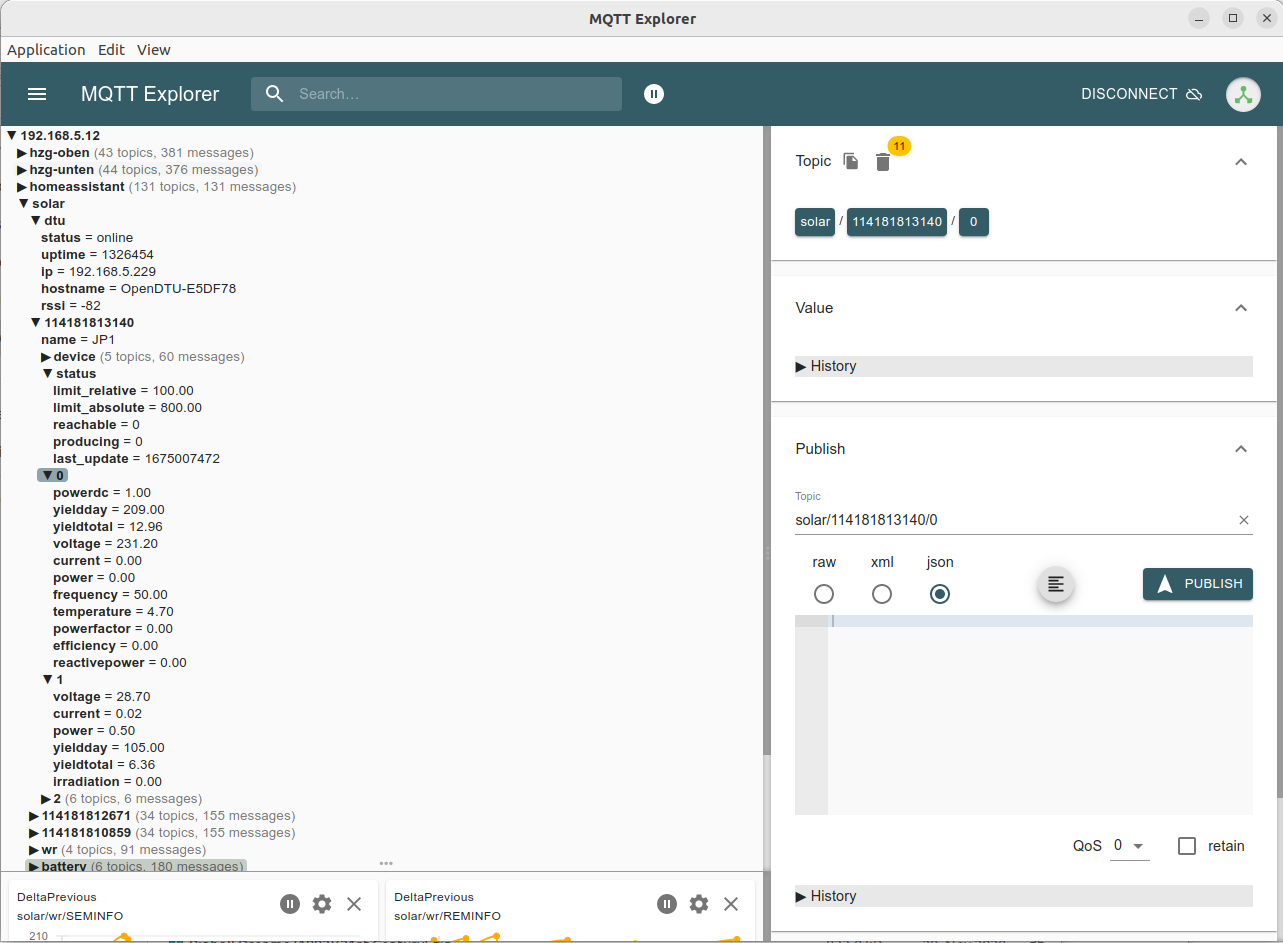
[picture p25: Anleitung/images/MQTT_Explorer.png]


=== Wechselrichter eintragen

.Settings -> Inverter Admin


In diesen Settings trägt man die Seriennummern der Inverter ein.
Auf den Invertern befindet sich die Seriennummer einmal als Aufkleber und einmal als Abziehaufkleber. 
Da das Gerät draußen ggf. die Beschriftung verliert, ist die Idee des Herstellers, den Aufkleber auf die DTU-Einheit zu kleben.
Wenn die Nummer verloren ist, hat man letztlich keine Chance den Wechselrichter jemals wieder abzufragen. Die Seriennummer ist wie der Schlüssel.

.Inverter Settings


Wenn der Inverter eingetragen ist, kann man mit dem Stiftsymbol weitere Detaileinstellungen pro Inverter machen.

==== Abfragerate und Sendeleistung

.Settings -> DTU Admin


OpenDTU erzeugt aus der Netzwerkkennung (MAC) für sich selber auch eine Seriennummer für die Verbindung mit den Wechselrichtern. 
Es dürfte wenig Sinn machen, die zu verändern, möglich ist es aber.

Die Abfragerate ist auf einmal alle 5 sec durch die Regularien zur Funknutzung begrenzt. Daher trifft maximal alle 5 sec. ein neuer Wert ein.
Bei schlechtem Empfang wird auch mal ein Datensatz fehlen.
Die Sendeleistung des Funkempfängers lässt sich erhöhen. Das hilft, wenn die Wechselrichter nicht mitbekommen, dass sie abgefragt werden.
Allerdings erhöhen sie selber wohl nicht die Sendeleistung, weshalb der Empfänger dann das schwache Signal der Wechselrichter korrekt empfangen muss.
Vermutlich wird es dann nur helfen, das OpenDTU-Gerät näher an die Wechselrichter zu bringen.

==== Firmware

.Firmware Upgrade


In diesem Dialog lässt sich die Firmware aktualisieren.
Allerdings muss die Firmware hinsichtlich Belegung der Signale am Prozessor auch passen! Man wird sie nicht im Internet finden.

Die installierte Firmware kann abweichend per MQTT relais=1/relais=0 das Relais ansteuern. 

[env:esp_solar]
 board = esp32dev
 build_flags = ${env.build_flags}
     -DHOYMILES_PIN_MISO=19
     -DHOYMILES_PIN_MOSI=23
     -DHOYMILES_PIN_SCLK=18
     -DHOYMILES_PIN_IRQ=15
     -DHOYMILES_PIN_CE=4
     -DHOYMILES
     _PIN_CS=5
    
==== Backup/Werksreset

.Config Management


In diesem Diealog kann man die Einstellungen sichern oder das Gerät auf den Werkszustand zurücksetzen.

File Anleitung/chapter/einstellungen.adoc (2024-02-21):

=== Wechselrichter

Man findet die individuellen Einstellungen pro Wechselrichter auf dem LiveView, der Willkommensseite nach dem Login.
Da die Steuerung pro Wechselrichter erfolgt, finden sich diese Bedienfelder -- nach Auswahl eines Wechselrichters (links) -- hinter dem Tacho, IO usw. Symbol (rechts soben).

==== Einspeiseleistung

.Limit Settings


Die Veränderung der Einspeiseleistung heißt hier Limit. 
Man wählt den Inverter und dann das kleine Tachosymbol. Dort gibt es dann die Einstellung als Betrag oder Prozentwert
"Set Limit persistent" und "Set Limit Non-Persistent".

Set Limit Persistant ist eine dauerhafte Einstellung und überdauert auch die nächste Nacht. 
Eine Einstellung mit Non-Persistant verfällt, sobald der Wechselrichter mangels Licht ausgeht.

==== Abschalten

.Power Settings


==== Inverterdaten

.Inverter Info


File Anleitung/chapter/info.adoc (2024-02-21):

=== Info  

Es gibt auch in OpenDTU Info-Seiten, um die System- und Netzwerkeinstellungen 
usw. zu kontrollieren. In den Systeminfos wird z.B. auch angezeigt, ob das Funkmodul erreichbar ist.

.Network Info

.NTP Info

.MqTT Info

.System Info

.Event log


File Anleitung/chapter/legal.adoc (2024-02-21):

[legal]
== Impressum

[cols="1",options="header"]
|====================
| Projektdaten: 
1+| Die beschriebene Baugruppe ist in privater Zeit, mit privaten Ressourcen, für private Zwecke entstanden.
1+| Da erkennbar war, dass sie auch für einfache wissenschaftliche 
Aufgaben nützlich sein könnte, ist sie dem Helmholtz Zentrum Hereon
gewidmet. 

Dies soll auf die wichtige gesellschaftliche Bedeutung der Forschung im Allgemeinen und des Zentrums im Besonderen hinweisen und Interesse dafür wecken.

1+| Die Baugruppe folgt als OpenHardware dem Lizenzgedanken der  GPL-2.0-Lizenz.

|====================

[cols="^1,^1,1,1",options="header"]
|====================
//2+| Hersteller: 
// 2+| Bevollmächtigter:  
//| a|  |  |  Helmholtz-Zentrum Hereon +
//Technikum +
//Herr John Hedde
4+| Das Forschungszentrum finden sie unter folgenen Angaben:
4+| Postfach: 1160
4+| Max-Planck-Str.1 
4+| DE 21502 Geesthacht
4+| Tel. +49 (0)4152 87-0
2+| info@hereon.de 
2+| http://www.hereon.de

//2+| john.hedde@hereon.de

|====================

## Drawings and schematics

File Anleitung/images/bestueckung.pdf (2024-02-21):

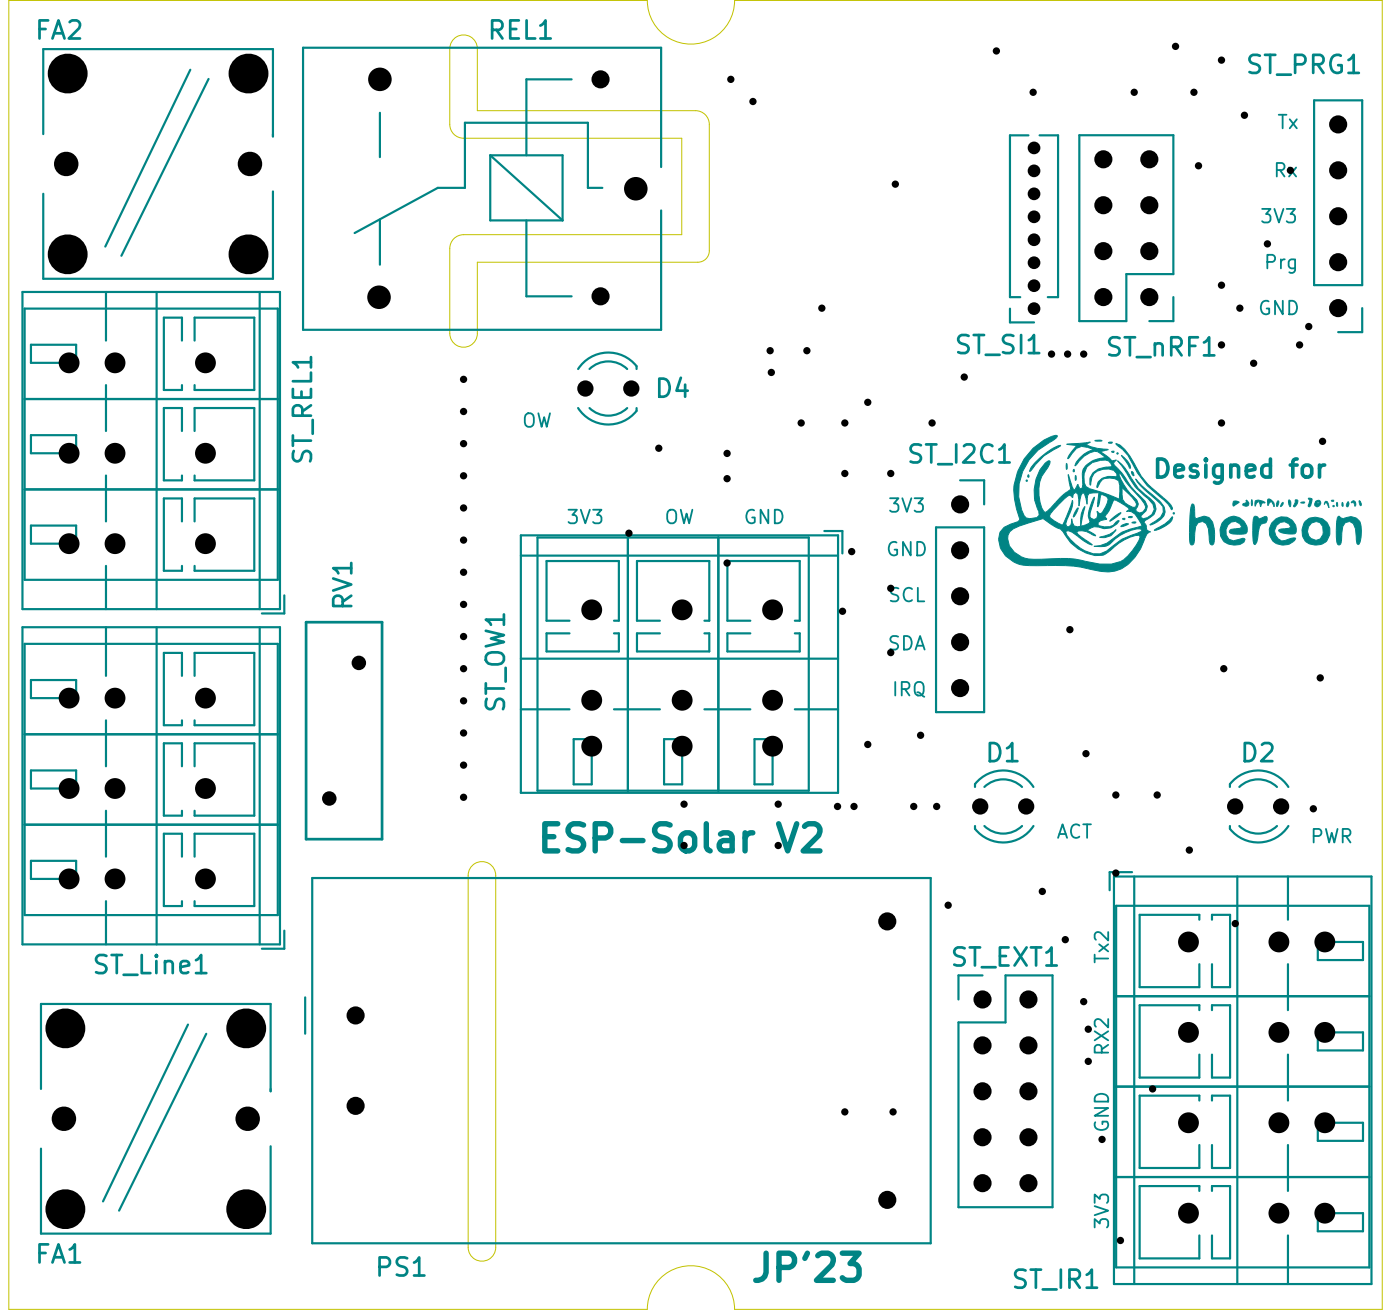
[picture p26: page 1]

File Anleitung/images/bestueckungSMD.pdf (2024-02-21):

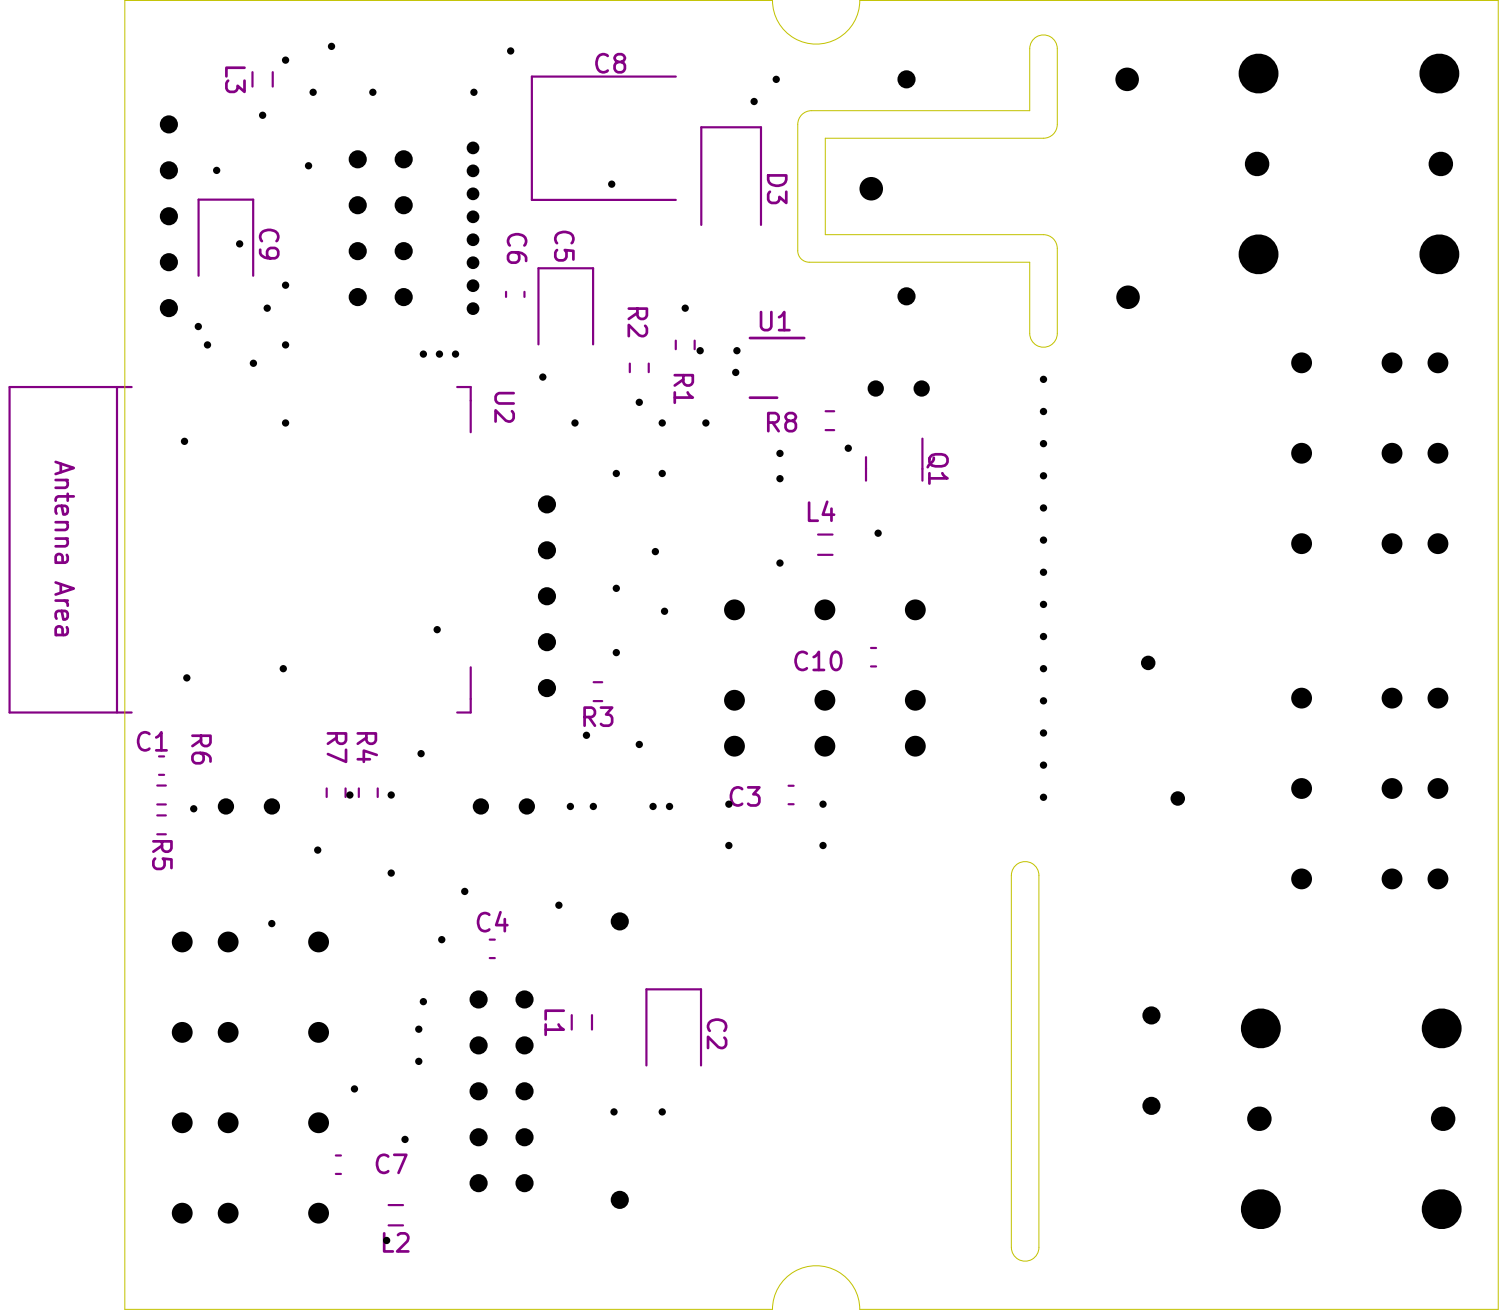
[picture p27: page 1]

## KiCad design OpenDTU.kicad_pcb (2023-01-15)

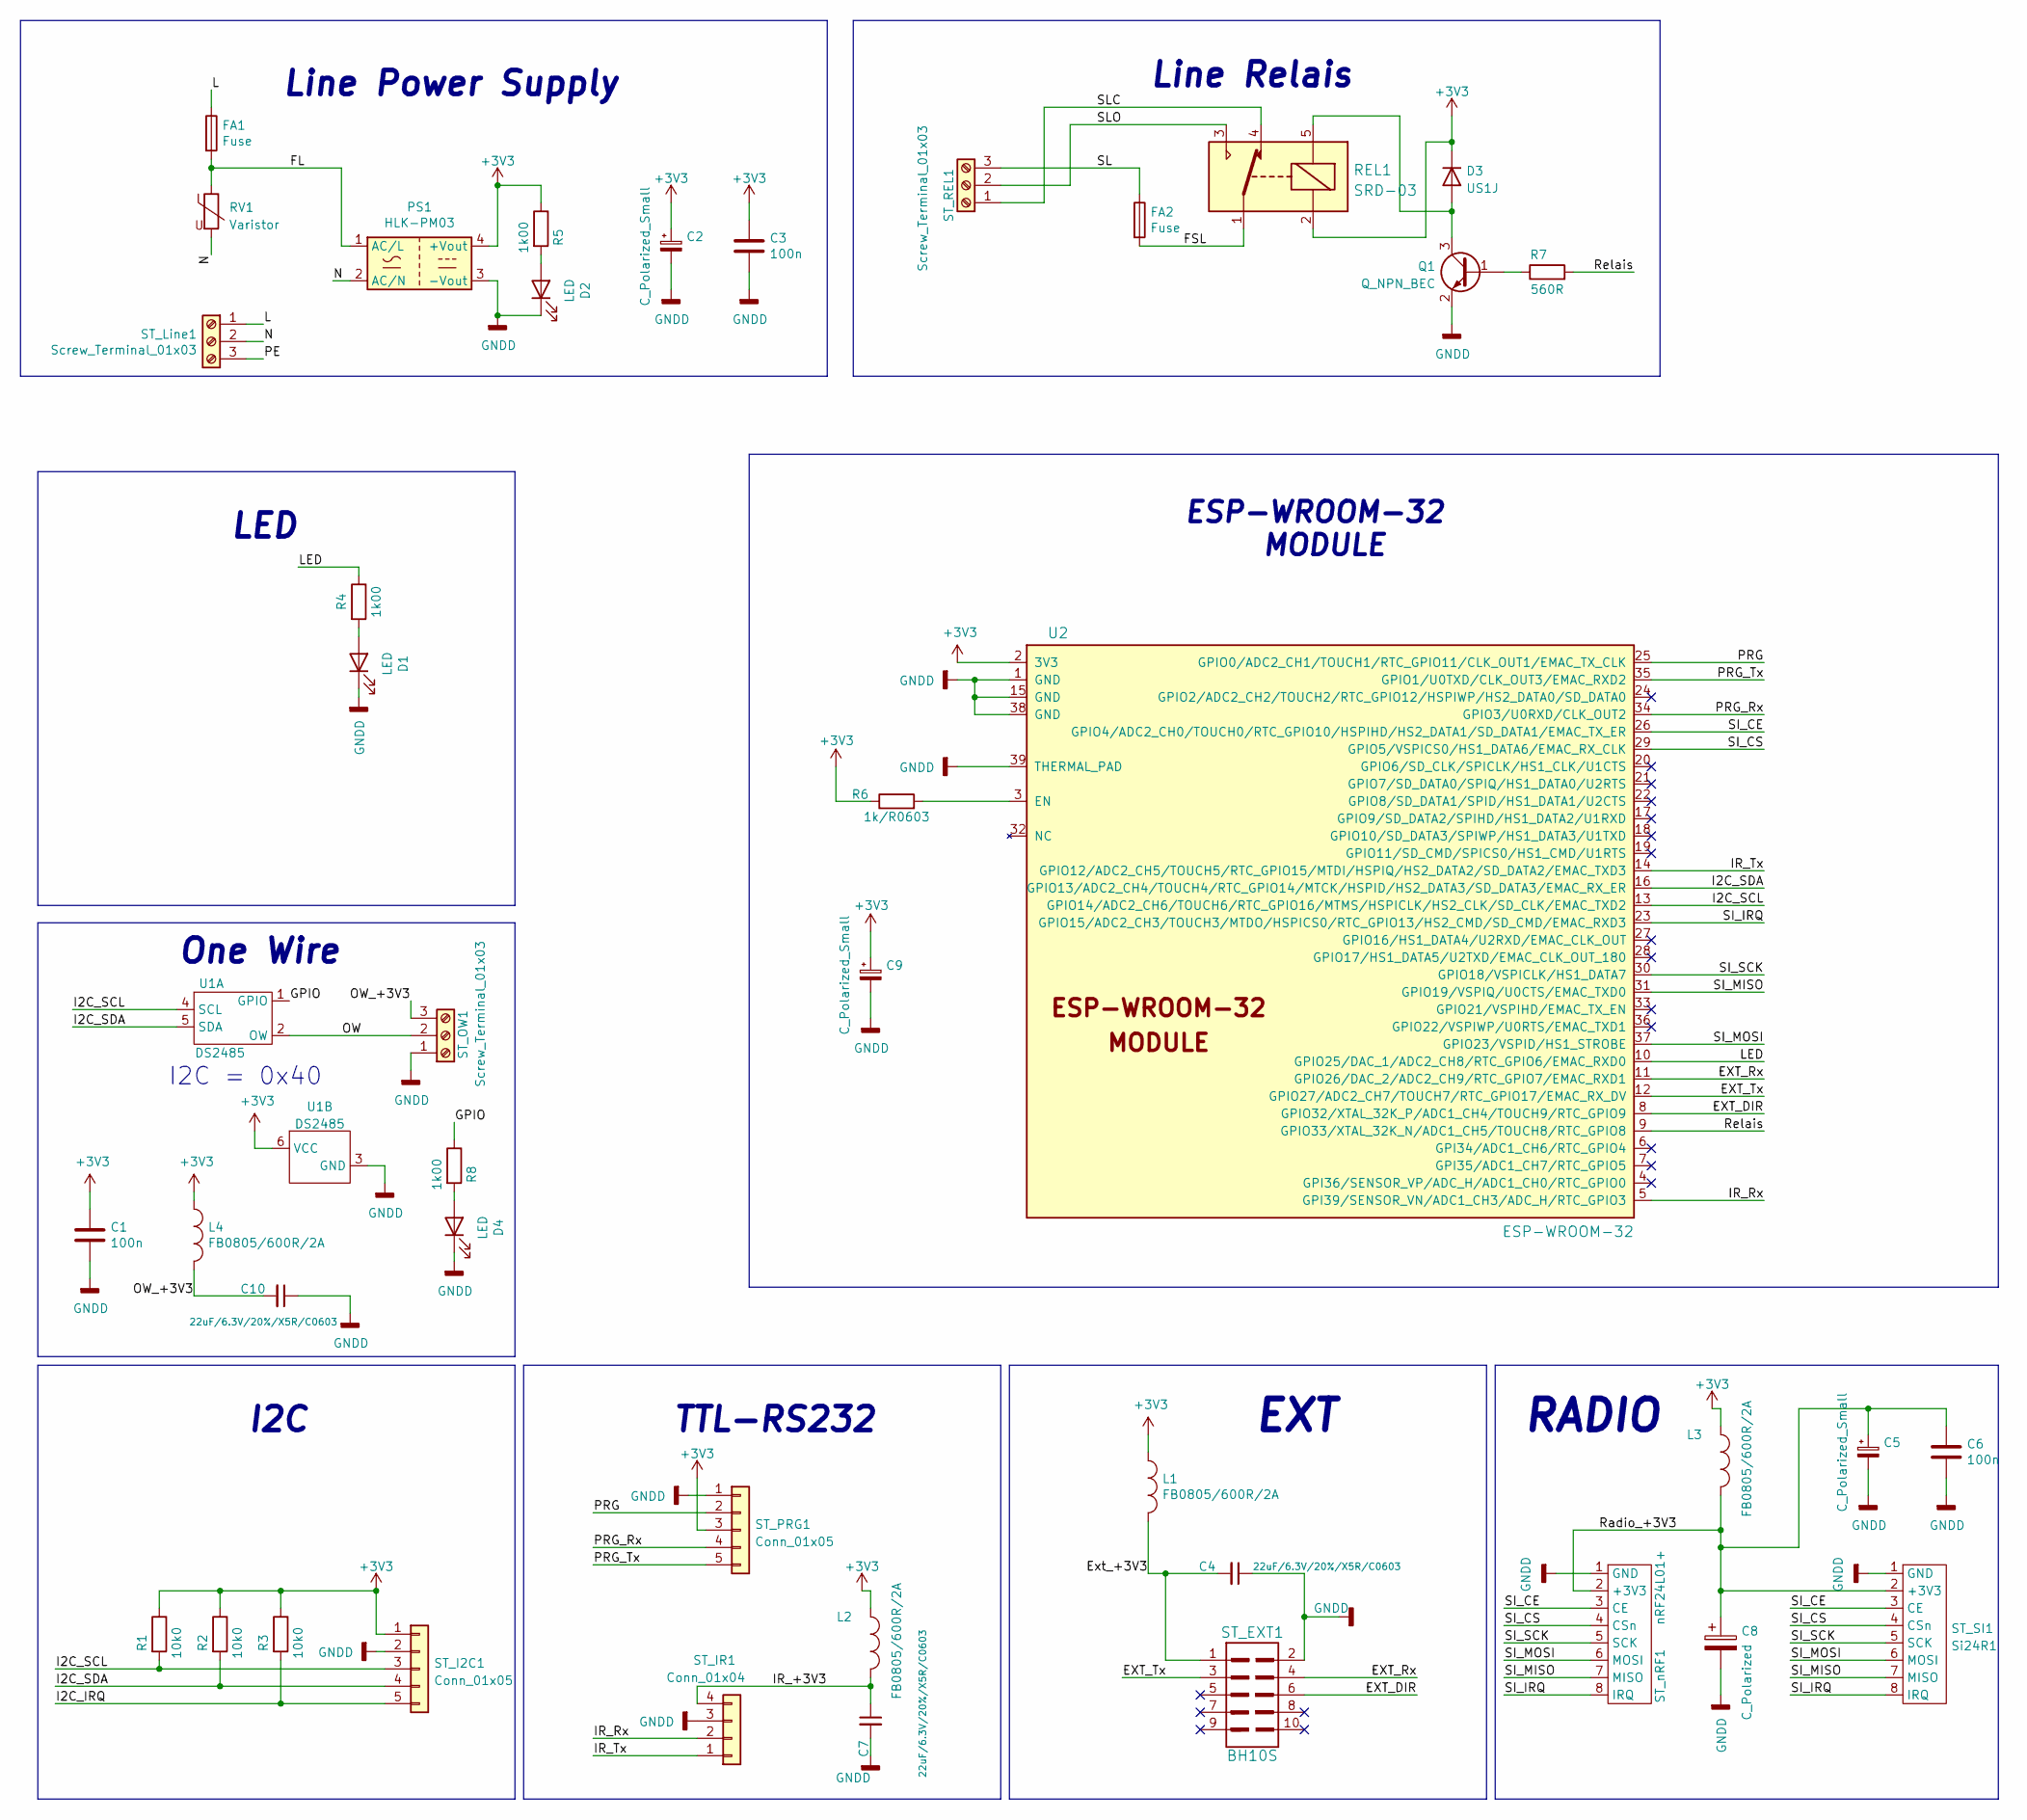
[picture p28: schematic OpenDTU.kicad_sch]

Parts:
C1, C3, C6: 100n; C_0603_1608Metric
C2, C5, C9: C_Polarized_Small; CP_EIA-3528-12_Kemet-T
C4, C7, C10: 22uF/6.3V/20%/X5R/C0603; C_0603_1608Metric
C8: C_Polarized; CP_EIA-7260-38_AVX-R
D1, D2, D4: LED; LED_D3.0mm_Clear
D3: US1J; D_SMA
FA1, FA2: Fuse; Fuseholder_Cylinder-5x20mm_Bulgin_FX0456_Vertical_Closed
L1, L2, L3, L4: FB0805/600R/2A; L_0805_2012Metric
PS1: HLK-PM03; Converter_ACDC_HiLink_HLK-PMxx
Q1: Q_NPN_BEC; SOT-23
R1, R2, R3: 10k0; R_0603_1608Metric
R4, R5, R8: 1k00; R_0603_1608Metric
R6: 1k/R0603; R_0603_1608Metric
R7: 560R; R_0603_1608Metric
REL1: SRD-03; Relay_SPDT_SANYOU_SRD_Series_Form_C
RV1: Varistor; RV_Disc_D12mm_W4.2mm_P7.5mm
ST_EXT1: BH10S; PinHeader_2x05_P2.54mm_Vertical
ST_I2C1: Conn_01x05; PinSocket_1x05_P2.54mm_Vertical
ST_IR1: Conn_01x04; TerminalBlock_WAGO_236-404_1x04_P5.00mm_45Degree
ST_Line1: Screw_Terminal_01x03; TerminalBlock_WAGO_236-403_1x03_P5.00mm_45Degree
ST_OW1: Screw_Terminal_01x03; TerminalBlock_WAGO_236-403_1x03_P5.00mm_45Degree
ST_PRG1: Conn_01x05; PinHeader_1x05_P2.54mm_Vertical
ST_REL1: Screw_Terminal_01x03; TerminalBlock_WAGO_236-403_1x03_P5.00mm_45Degree
ST_SI1: Si24R1; PinSocket_1x08_P1.27mm_Vertical
ST_nRF1: nRF24L01+; PinHeader_2x04_P2.54mm_Vertical
U1: DS2485; DFN-6-1EP_3x3mm_P0.95mm_EP1.7x2.6mm
U2: ESP-WROOM-32; ESP32-WROOM-32E

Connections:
+3V3: C1.1, C2.1, C3.1, C9.1, D3.1 (K), L1.1, L2.1, L3.1, L4.1, PS1.4 (+Vout), R1.1, R2.1, R3.1, R5.1, R6.1, REL1.2, ST_I2C1.1, ST_PRG1.3, U1.6 (VCC), U2.2 (3V3)
/EXT_DIR: ST_EXT1.6, U2.8 (GPIO32/XTAL_32K_P/ADC1_CH4/TOUCH9/RTC_G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)
/EXT_Rx: ST_EXT1.4, U2.11 (GPIO26/DAC_2/ADC2_CH9/RTC_GPIO7/EMAC_RX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)
/EXT_Tx: ST_EXT1.3, U2.12 (GPIO27/ADC2_CH7/TOUCH7/RTC_GPIO17/EMAC_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)
/Ext_+3V3: C4.2, L1.2, ST_EXT1.1
/FL: FA1.2, PS1.1 (AC/L), RV1.1
/FSL: FA2.2, REL1.1
/GPIO: R8.1, U1.1 (GPIO)
/I2C_IRQ: R3.2, ST_I2C1.5
/I2C_SCL: R1.2, ST_I2C1.3, U1.4 (SCL), U2.13 (GPIO14/ADC2_CH6/TOUCH6/RTC_GPIO16/MTMS/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)
/I2C_SDA: R2.2, ST_I2C1.4, U1.5 (SDA), U2.16 (GPIO13/ADC2_CH4/TOUCH4/RTC_GPIO14/MTCK/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)
/IR_+3V3: C7.1, L2.2, ST_IR1.4
/IR_Rx: ST_IR1.2, U2.5 (GPI39/SENSOR_VN/ADC1_CH3/ADC_H/RTC_GPIO3)
/IR_Tx: ST_IR1.1, U2.14 (GPIO12/ADC2_CH5/TOUCH5/RTC_GPIO15/MTDI/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)
/L: FA1.1, ST_Line1.1
/LED: R4.1, U2.10 (GPIO25/DAC_1/ADC2_CH8/RTC_GPIO6/EMAC_RX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)
/N: PS1.2 (AC/N), RV1.2, ST_Line1.2
/OW: ST_OW1.2, U1.2 (OW)
/OW_+3V3: C10.2, L4.2, ST_OW1.3
/PE: ST_Line1.3
/PRG: ST_PRG1.2, U2.25 (GPIO0/ADC2_CH1/TOUCH1/RTC_GPIO11/CLK_OU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)
/PRG_Rx: ST_PRG1.4, U2.34 (GPIO3/U0RXD/CLK_OUT2)
/PRG_Tx: ST_PRG1.5, U2.35 (GPIO1/U0TXD/CLK_OUT3/EMAC_RXD2)
/Radio_+3V3: C5.1, C6.1, C8.1, L3.2, ST_SI1.2 (+3V3), ST_nRF1.2 (+3V3)
/Relais: R7.2, U2.9 (GPIO33/XTAL_32K_N/ADC1_CH5/TOUCH8/RTC_G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)
/SI_CE: ST_SI1.3 (CE), ST_nRF1.3 (CE), U2.26 (GPIO4/ADC2_CH0/TOUCH0/RTC_GPIO10/HSPIHD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)
/SI_CS: ST_SI1.4 (CSn), ST_nRF1.4 (CSn), U2.29 (GPIO5/VSPICS0/HS1_DATA6/EMAC_RX_CLK)
/SI_IRQ: ST_SI1.8 (IRQ), ST_nRF1.8 (IRQ), U2.23 (GPIO15/ADC2_CH3/TOUCH3/MTDO/HSPICS0/RTC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)
/SI_MISO: ST_SI1.7 (MISO), ST_nRF1.7 (MISO), U2.31 (GPIO19/VSPIQ/U0CTS/EMAC_TXD0)
/SI_MOSI: ST_SI1.6 (MOSI), ST_nRF1.6 (MOSI), U2.37 (GPIO23/VSPID/HS1_STROBE)
/SI_SCK: ST_SI1.5 (SCK), ST_nRF1.5 (SCK), U2.30 (GPIO18/VSPICLK/HS1_DATA7)
/SL: FA2.1, ST_REL1.3
/SLC: REL1.4, ST_REL1.1
/SLO: REL1.3, ST_REL1.2
GNDD: C1.2, C2.2, C3.2, C4.1, C5.2, C6.2, C7.2, C8.2, C9.2, C10.1, D1.1 (K), D2.1 (K), D4.1 (K), PS1.3 (-Vout), Q1.2 (E), ST_EXT1.2, ST_I2C1.2, ST_IR1.3, ST_OW1.1, ST_PRG1.1, ST_SI1.1 (GND), ST_nRF1.1 (GND), U1.3 (GND), U2.1 (GND), U2.15 (GND), U2.38 (GND), U2.39 (THERMAL_PAD)
unnamed: D1.2 (A), R4.2
unnamed: D2.2 (A), R5.2
unnamed: D3.2 (A), Q1.3 (C), REL1.5
unnamed: D4.2 (A), R8.2
unnamed: Q1.1 (B), R7.1
unnamed: R6.2, U2.3 (EN)

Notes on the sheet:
I2C = 0x40
Line Relais
LED
EXT
ESP-WROOM-32 MODULE
RADIO
I2C
Line Power Supply
One Wire
TTL-RS232

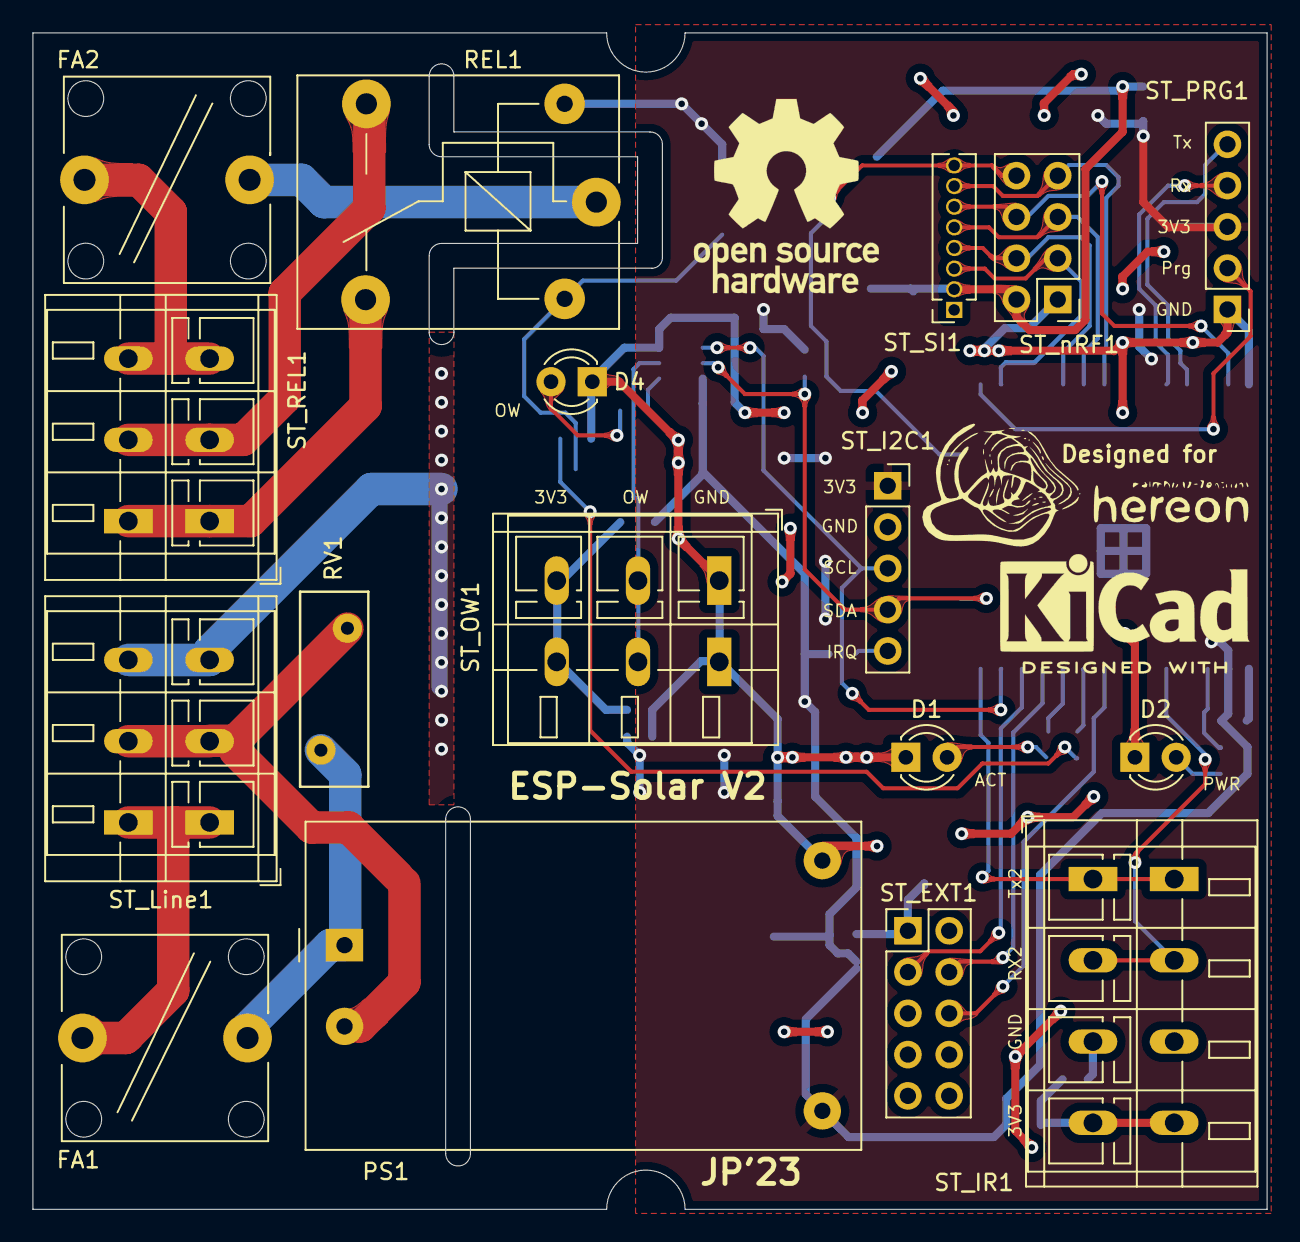
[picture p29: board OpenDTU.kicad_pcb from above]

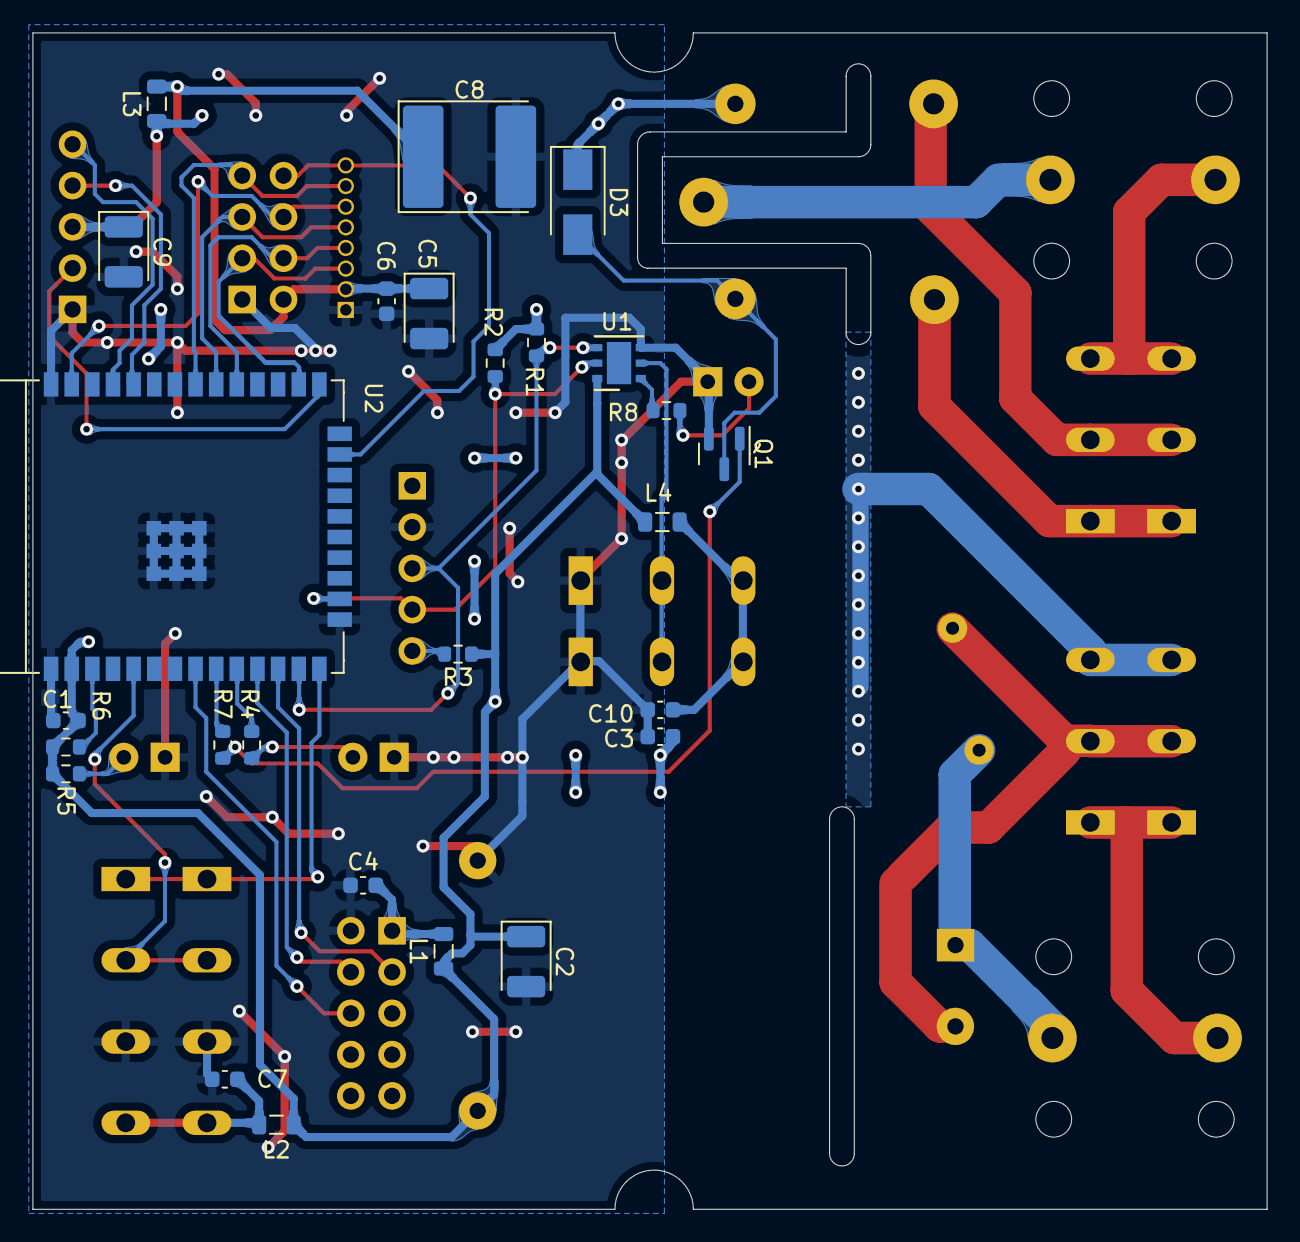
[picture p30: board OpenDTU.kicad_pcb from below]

Board: 2 copper layers, 75.9 x 72.4 mm, 43 parts (26 on the bottom side), 40 nets.
